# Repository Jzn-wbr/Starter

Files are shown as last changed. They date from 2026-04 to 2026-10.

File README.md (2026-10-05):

<div align="center">

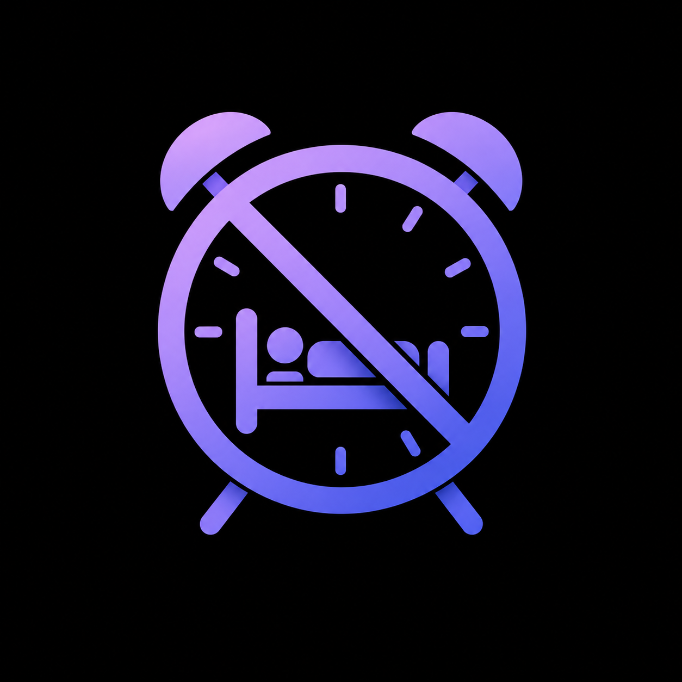
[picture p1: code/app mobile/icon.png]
Logo de l’application mobile Réveil


# Réveil

### Un réveil qui vous aide vraiment à sortir du lit.

Un système de réveil connecté qui combine une station audio, un bracelet de mouvement et une application mobile pour transformer le réveil en un vrai départ de journée.

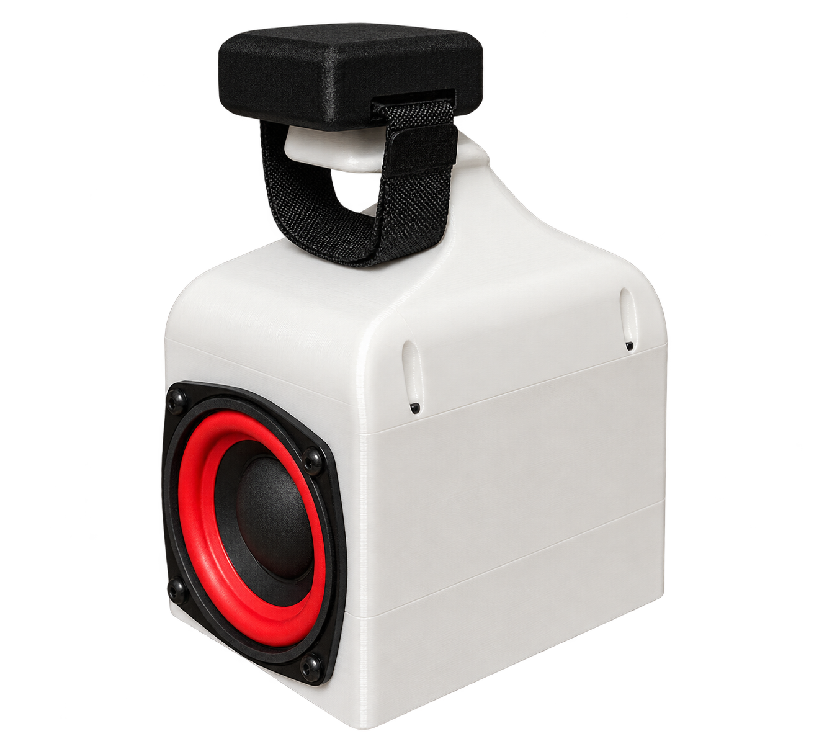
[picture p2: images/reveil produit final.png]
Version finale de la station audio


**Projet personnel · Version finale du produit**

</div>

## L’idée

Les réveils classiques s’arrêtent d’une pression sur un bouton. Celui-ci est pensé pour rendre le retour au sommeil beaucoup plus difficile : l’alarme démarre à l’heure choisie et ne se calme qu’après avoir détecté une activité réelle grâce au bracelet.

Pas de bouton snooze. Pas de négociation avec soi-même à 7 h 30.

## Une expérience en trois éléments

| | Rôle |
| --- | --- |
| **La station** | Le centre du système : elle déclenche l’alarme, diffuse la musique et supervise le réveil. |
| **Le bracelet** | Il détecte les mouvements et confirme que la journée a réellement commencé. |
| **L’application** | Elle permet de choisir l’heure, la musique et de vérifier que les appareils sont prêts. |

<p align="center">
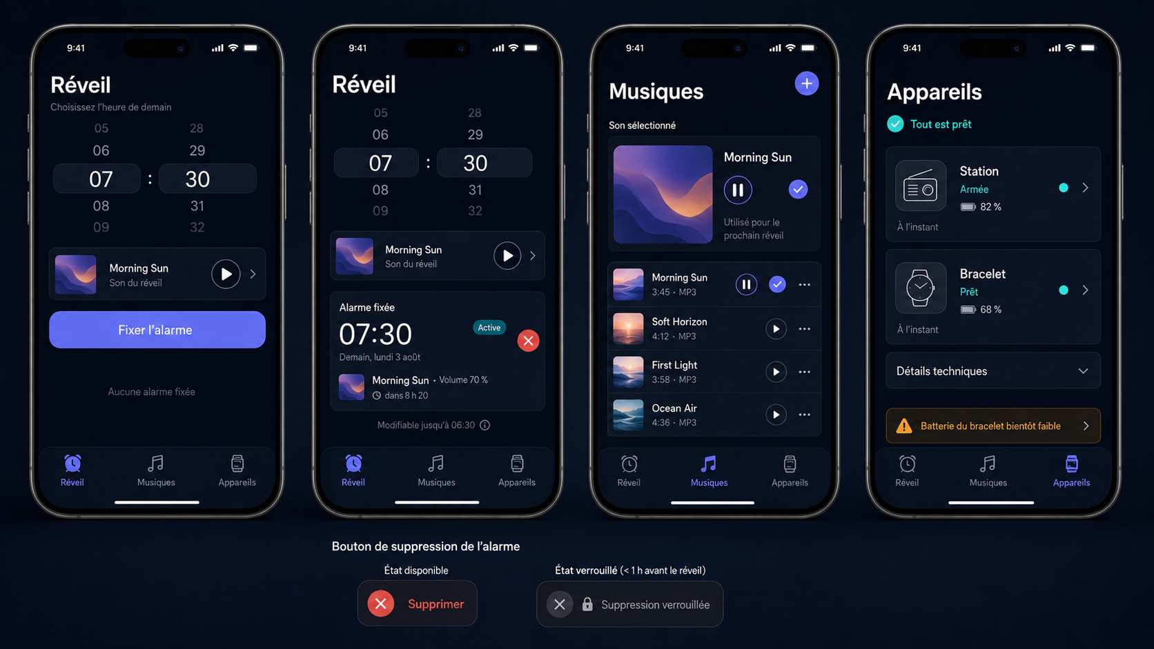
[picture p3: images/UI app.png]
Interface mobile de configuration du réveil
  
</p>

## Comment ça marche

1. Choisissez une heure et votre son de réveil dans l’application.
2. La station se prépare pour le lendemain et synchronise la configuration.
3. À l’heure prévue, la musique démarre sur la station.
4. Le bracelet mesure votre activité pendant une fenêtre dédiée.
5. Quand le mouvement est confirmé, le réveil peut enfin s’arrêter.

L’objectif : remplacer le réflexe « encore cinq minutes » par un réveil plus franc, plus personnel et plus difficile à ignorer.

## En images

<div align="center">
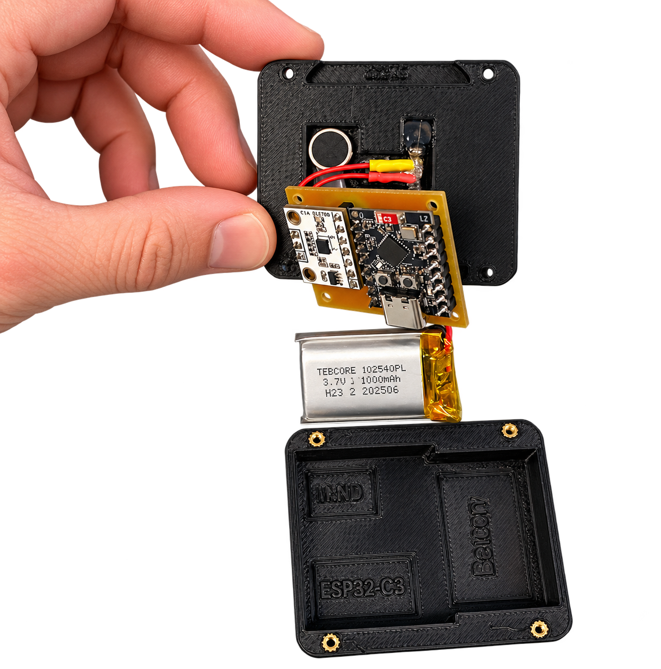
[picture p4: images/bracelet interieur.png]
Électronique et batterie du bracelet
  
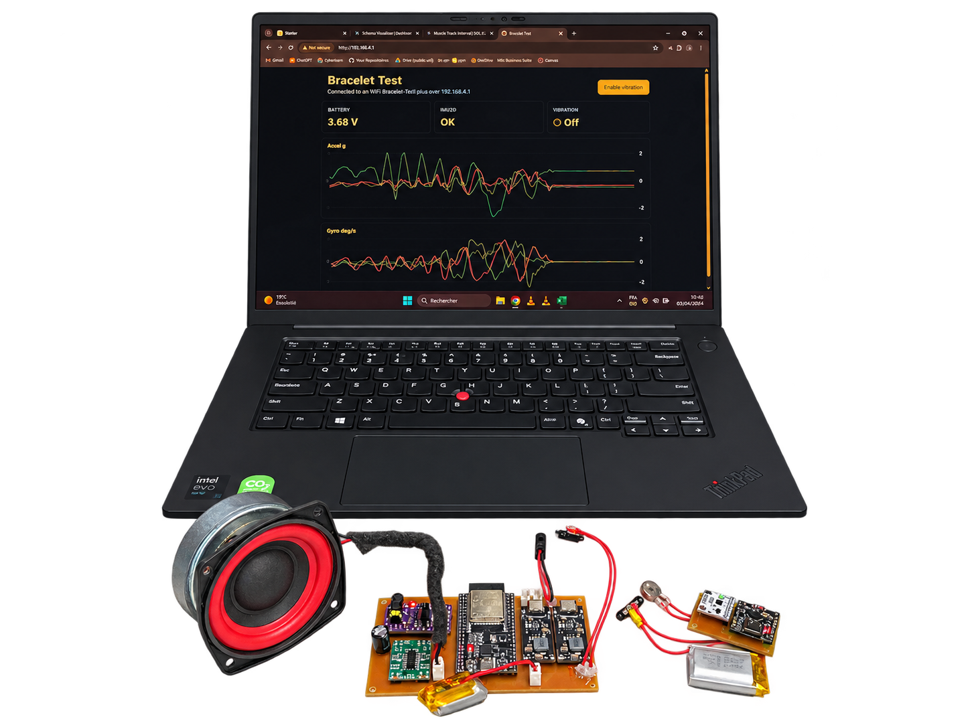
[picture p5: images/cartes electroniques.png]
Cartes électroniques et station audio
  
</div>

## Une base ouverte pour un objet complet

Ce dépôt rassemble l’application mobile, le firmware de la station, le firmware du bracelet, les schémas électroniques et la documentation du système. Il présente la version finale du produit, pensée comme un réveil fiable, agréable à utiliser et réellement efficace.

> Le système est conçu pour un usage personnel. Les choix techniques et les fonctionnalités peuvent encore évoluer.

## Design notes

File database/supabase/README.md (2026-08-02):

# Supabase v1 schema

`v1_schema.sql` is the concrete database contract for the personal wake-up prototype.

Apply it in the Supabase SQL editor or through the Supabase CLI against the target project. It creates:

- `alarm_plan`
- `alarm_audio_selection`
- `music_tracks`
- `station_status`
- `bracelet_status`
- storage bucket `wake-up-music`
- prototype-only anon read/write policies

The anon policies are intentionally permissive for the no-auth v1 prototype. They are not production-ready security.

## V1 table split

The schema intentionally keeps one active `main` row per responsibility:

- `alarm_plan`: whether and when the next alarm should happen.
- `alarm_audio_selection`: what the next alarm should play and at what volume.
- `music_tracks`: uploaded wake-up sounds.
- `station_status`: station state and station-side problem reporting.
- `bracelet_status`: latest bracelet state, energy window, vibration state, and battery voltage as seen and published by the station.

This split favors readability over the smallest possible number of Supabase reads. The station should load `alarm_plan` and `alarm_audio_selection` together, then cache the last valid combined configuration locally.
Bracelet energy remains station-side alarm input; the station does not stream energy to Supabase at bracelet telemetry rate.

This file is the current v1 schema, not a reversible migration. If an older prototype database already contains `alarm_config` or `device_status`, migrate or drop those old tables manually after preserving any data you still need.

## Mermaid overview

```mermaid
erDiagram
  MUSIC_TRACKS {
    text id PK
    text title
    text storage_path UK
    text public_url
    boolean is_available
    timestamptz created_at
  }

  ALARM_PLAN {
    text id PK "always main"
    boolean enabled
    date alarm_date
    time alarm_time
    text timezone
    integer revision
    timestamptz updated_at
  }

  ALARM_AUDIO_SELECTION {
    text id PK "always main"
    audio_source_v1 audio_source
    text selected_track_id FK
    integer volume_percent
    timestamptz updated_at
  }

  STATION_STATUS {
    text id PK "always main"
    station_state_v1 station_state
    problem_code_v1 problem_code
    text problem_message
    integer active_alarm_revision
    numeric station_battery_voltage
    timestamptz updated_at
  }

  BRACELET_STATUS {
    text id PK "always main"
    bracelet_state_v1 bracelet_state
    problem_code_v1 problem_code
    text problem_message
    numeric bracelet_battery_voltage
    bigint bracelet_last_seen_ms
    integer bracelet_energy
    integer bracelet_energy_valid_ms
    integer bracelet_energy_threshold
    integer energy_mute_remaining_ms
    boolean bracelet_vibrating
    timestamptz updated_at
  }

  MUSIC_TRACKS ||--o| ALARM_AUDIO_SELECTION : selected_by
```

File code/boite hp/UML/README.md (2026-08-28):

# Station UML

This folder contains PlantUML source files for the bedside station firmware architecture.

Rules:

- Commit `.puml` source files.
- Update diagrams manually when architecture, state machines, module boundaries, ESP-NOW flow, Supabase flow, audio flow, fallback behavior, or fault handling changes.
- Do not regenerate diagrams automatically during normal PlatformIO builds.
- Generated image exports such as `.png` or `.svg` are optional local review artifacts; the `.puml` files are the source of truth.

Suggested starting diagrams:

- `station_state_machine.puml`
- `communication_flow.puml`

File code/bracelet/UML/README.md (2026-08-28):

# Bracelet UML

This folder contains PlantUML source files for the bracelet firmware architecture.

Rules:

- Commit `.puml` source files.
- Update diagrams manually when architecture, state machines, module boundaries, BMI270 flow, activity validation, ESP-NOW telemetry, battery readiness, or fault handling changes.
- Do not regenerate diagrams automatically during normal PlatformIO builds.
- Generated image exports such as `.png` or `.svg` are optional local review artifacts; the `.puml` files are the source of truth.

Suggested starting diagrams:

- `bracelet_firmware_flow.puml`
- `esp_now_packet_flow.puml`

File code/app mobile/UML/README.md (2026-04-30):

# Mobile App UML

This folder contains PlantUML source files for the mobile PWA.

Rules:

- Commit `.puml` source files.
- Keep at least one UML use-case diagram for the v1 app workflow.
- Update diagrams manually when app use cases, user-facing flows, Supabase behavior, or status display behavior changes.
- Do not regenerate diagrams automatically during normal app builds or dev-server runs.
- Generated image exports such as `.png` or `.svg` are optional local review artifacts; the `.puml` files are the source of truth.

Current diagrams:

- `use_cases.puml`

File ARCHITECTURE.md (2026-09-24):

# System Architecture And Contracts

This file defines the shared contracts between the three code areas:

- `code/app mobile`: Vue/Vite PWA.
- `code/boite hp`: bedside station firmware.
- `code/bracelet`: bracelet firmware.

Each subsystem should be developed independently against these contracts. Do not change a contract without updating this file and the affected `AGENTS.md` files.

## Core Architecture

The station is the central alarm authority. The app configures the alarm through Supabase. The bracelet only reports activity to the station.

Target v1 communication paths:

- App -> Supabase: upload music, select music, configure next alarm.
- Station -> Supabase: read alarm plan, read selected music URL, write station/problem state.
- Bracelet -> Station: send activity and battery/fault telemetry over ESP-NOW.
- Station -> Bracelet: send ESP-NOW control messages such as current alarm phase, acknowledgements, vibration requests, or threshold profile.
- App -> Station: no direct communication in v1.
- App -> Bracelet: no direct communication in v1.
- Bracelet -> Supabase: no direct communication in v1.

ESP-NOW is the target station/bracelet link. The station remains associated with the configured home WiFi for NTP, Supabase, and music streaming, while ESP-NOW shares the station's current 2.4 GHz channel. The bracelet does not join the router: it scans ESP-NOW channels until a valid paired station control is found, locks to that channel while controls continue, and resumes scanning after a control timeout. ESP-NOW range, channel reacquisition, latency, and battery life must be tested physically.

## Supabase V1 Schema

Use these exact table names and field names for v1 unless this file is updated first. The concrete Supabase SQL definition is in `database/supabase/v1_schema.sql`. The app and station must code against that SQL schema.

The v1 schema is prototype-only from a security perspective: anon clients may read and write the v1 tables and the public wake-up music bucket. This is acceptable only for the personal no-auth prototype, not for production.

### `alarm_plan`

Single active-row table for whether and when the next wake-up should happen.

- `id`: text, always `main` for v1.
- `enabled`: boolean.
- `alarm_date`: SQL `date`, local date for the next alarm.
- `alarm_time`: SQL `time without time zone`, `HH:MM` 24-hour local time at the app/station boundary.
- `timezone`: IANA timezone string, for example `Europe/Zurich`.
- `revision`: integer incremented by the app on each saved config.
- `updated_at`: SQL `timestamptz`, updated automatically by the database on row update.

### `alarm_audio_selection`

Single active-row table for what the next wake-up should play.

- `id`: text, always `main` for v1.
- `audio_source`: `track` or `fallback`; `fallback` means the local station fallback sound is intentionally selected.
- `selected_track_id`: text referencing `music_tracks.id`; required when `audio_source` is `track`, null when `audio_source` is `fallback`.
- `volume_percent`: integer `0..100`, playback volume requested for the next alarm.
- `updated_at`: SQL `timestamptz`, updated automatically by the database on row update.

Station rule: cache the last valid combined alarm configuration from `alarm_plan` and `alarm_audio_selection` locally. If Supabase is unreachable later but the cached config is still for the next alarm and the station has valid time, the station may use the cached config.

### `music_tracks`

Library of uploaded wake-up sounds.

- `id`: text primary key, generated as a UUID string by default.
- `title`: display name shown in the app.
- `storage_path`: Supabase Storage path.
- `public_url`: playable URL used by the station in the no-auth prototype.
- `is_available`: boolean.
- `created_at`: SQL `timestamptz`.

Use the Supabase Storage bucket `wake-up-music` for uploaded audio files. V1 allows `audio/mpeg`, `audio/wav`, `audio/ogg`, and `audio/mp4` up to 50 MiB per file.

Avoid storing duration, waveform, tags, statistics, playlist order, or user metadata before v1 needs them.

### `station_status`

Single station-published status row read by the app.

- `id`: text, always `main` for v1.
- `station_state`: one of the station states below.
- `problem_code`: one of the problem codes below, or `none`.
- `problem_message`: short human-readable diagnostic text.
- `active_alarm_revision`: latest `alarm_plan.revision` loaded by the station.
- `station_battery_voltage`: station battery terminal voltage in volts, or `null` if unknown.
- `updated_at`: SQL `timestamptz`, updated automatically by the database on row update.

The app reads this status. The app must not infer alarm authority from it.

### `bracelet_status`

Single station-published row for the latest bracelet state as seen by the station.

- `id`: text, always `main` for v1.
- `bracelet_state`: latest bracelet state as seen by the station, or `unknown`.
- `problem_code`: one of the problem codes below, or `none`.
- `problem_message`: short human-readable diagnostic text.
- `bracelet_battery_voltage`: bracelet battery terminal voltage in volts, or `null` if unknown.
- `bracelet_last_seen_ms`: station uptime timestamp for the last bracelet packet, or `null`.
- `bracelet_energy`: latest 200 ms energy window reported by the bracelet.
- `bracelet_energy_valid_ms`: measured time inside that 200 ms window, excluding vibration and settling time.
- `bracelet_energy_threshold`: station threshold used to mute alarm audio for v1. The current firmware default is `1000000`.
- `energy_mute_remaining_ms`: remaining station-side mute time produced by bracelet energy.
- `bracelet_vibrating`: whether the bracelet vibration motor is currently active.
- `updated_at`: SQL `timestamptz`, updated automatically by the database on row update.

The app reads this status. The bracelet does not write to Supabase in v1.

### Problem Codes

Use these v1 problem codes:

- `none`
- `supabase_unavailable`
- `time_unknown`
- `no_valid_alarm_config`
- `music_stream_failed`
- `fallback_audio_failed`
- `bracelet_missing`
- `bracelet_low_battery`
- `sensor_fault`

## System States

The station should expose one clear state at a time:

- `idle`: no alarm armed.
- `armed`: next alarm is configured and valid.
- `ringing`: alarm audio is active.
- `validating_activity`: alarm is active and bracelet activity is being evaluated.
- `stopped`: alarm window ended after bracelet activity monitoring.
- `fault`: alarm cannot run correctly because of a blocking issue.

The bracelet should expose:

- `ready`: enough battery and sensor link is usable.
- `low_battery`: battery may be insufficient for reliable wake-up validation.
- `fault`: sensor, power, or firmware state prevents reliable validation.

The app should display station and bracelet states without becoming the alarm authority.

## Station State Transitions

Allowed station transitions for v1:

- `idle -> armed`: app has saved a valid enabled alarm and station loaded it.
- `idle -> fault`: blocking configuration, time, audio, or bracelet readiness problem.
- `armed -> idle`: app disables the next alarm.
- `armed -> ringing`: alarm time is reached and prerequisites are valid.
- `armed -> fault`: a blocking problem appears before alarm time.
- `ringing -> validating_activity`: bracelet energy reaches `1000000` during the alarm window, so alarm audio is muted for 10 seconds while monitoring continues.
- `ringing -> ringing`: bracelet packets are lost for more than `3s`; publish `bracelet_missing`, keep alarm audio playing, and resume movement detection automatically when packets return.
- `ringing -> fault`: station audio output fails.
- `ringing -> stopped`: the 10-minute alarm activity window has ended.
- `validating_activity -> ringing`: the 10-second energy mute and the pre-unmute warning of up to three bracelet vibrations expire before the 10-minute window has ended.
- `validating_activity -> stopped`: the 10-minute alarm activity window has ended.
- `validating_activity -> validating_activity`: bracelet packets are lost for more than `3s`; publish `bracelet_missing` but honor the remaining confirmed movement mute.
- `validating_activity -> ringing`: the confirmed movement mute expires and no vibration acknowledgement or new movement event prevents audio from resuming.
- `validating_activity -> fault`: station audio output fails.
- `stopped -> idle`: alarm cycle is complete.
- `fault -> idle`: user fixes the issue and station reloads a valid disabled/no-alarm state.
- `fault -> armed`: user fixes the issue and station reloads a valid enabled alarm.

Do not add a normal stop or snooze transition from `ringing` or `validating_activity`. The v1 alarm stops only when the fixed 10-minute activity window ends; bracelet energy only mutes alarm audio during that window.

When the bracelet observes the station transition from `ringing` or `validating_activity` to `stopped`, it emits one completion signal made of four fast vibration pulses. Each pulse lasts `150ms` and starts `300ms` after the previous one. This local indication means the 10-minute wake-up window is complete and the bracelet may be removed. Repeated `stopped` controls do not replay the signal.

## Failure Policy

The product is designed by the lucid user from the evening for the tired user in the morning. Battery preparation and normal readiness are the user's responsibility: the bracelet should be placed on the station and the station should be plugged in overnight.

If there is a blocking bug or technical fault that prevents normal operation, the station should not create a fake sense of reliability. It should enter `fault`, avoid starting a broken alarm flow, and publish a clear problem state for the app.

Blocking faults before alarm start include:

- No valid combined `alarm_plan` and `alarm_audio_selection` can be loaded and no valid cached config exists.
- Bracelet is missing or not ready when bracelet validation is required.
- Bracelet battery is below the required threshold.
- Bracelet reports `fault`.
- Station cannot determine time.
- Station audio output cannot be initialized.

Music streaming failure is not a reason to skip the alarm. If the selected Supabase music cannot be streamed at wake-up time, the station must use a small local fallback alarm sound that fits ESP memory constraints.

Network or Supabase failures should be visible in station logs and in app-readable status when possible.

If the bracelet disappears for more than `3s` while ringing, publish `bracelet_missing` and keep alarm audio playing. If a confirmed movement mute is already active, honor its original deadline instead of cancelling it; once it expires, resume audio after the vibration acknowledgement policy below. When packets return, clear the missing problem and process any still-valid retransmitted movement event. Do not mark the alarm revision complete because of bracelet packet loss. If station audio itself fails, prefer `fault` over a fake alarm state.

## Battery Readiness Contract

Use these v1 defaults unless physical testing proves they are wrong:

- Bracelet `ready`: battery is at least `30%` and sensor init succeeds.
- Bracelet `low_battery`: battery is below `30%`.
- Bracelet blocking low battery: battery is below `20%` before alarm start.
- Station should publish `bracelet_low_battery` before bedtime if seen.
- Station should enter `fault` before alarm start if bracelet battery is below the blocking threshold.

If battery voltage cannot be measured yet, report `null` and document the limitation. Do not fake battery precision.

Supabase stores raw battery voltage for station and bracelet status. User-facing battery percentages are derived by the PWA from the voltage, so changing the display curve does not require a database migration.

Station battery voltage is measured on station GPIO34 through a 2:1 voltage divider: `Vbat = 2 * Vadc`.

## Bracelet/Station ESP-NOW Contract

Use compact binary packets. All packets start with:

- `magic`: uint32 value identifying Starter traffic before any packet is parsed.
- `protocol_version`: `6`. Older packets are rejected; station and bracelet firmware must be updated together.
- `message_type`: enum below.
- `sender_role`: `station` or `bracelet`.
- `device_id`: 6-byte MAC address.
- `sequence`: uint32 incrementing counter.
- `uptime_ms`: uint32 sender uptime.

### Message Types

- `1`: `bracelet_status`, bracelet -> station.
- `2`: `station_control`, station -> bracelet.

### ESP-NOW `bracelet_status` Packet

Fields:

- `bracelet_state`: enum from System States.
- `battery_voltage_mv`: uint16 bracelet battery terminal voltage in millivolts, or `0` if unknown.
- `fault_code`: problem code enum, or `none`.
- `vibrating`: boolean indicating whether the vibration motor is currently active.
- `energy`: uint32 energy measured over the latest 200 ms window.
- `energy_valid_ms`: uint16 measured milliseconds in that window, excluding bracelet vibration/settling.
- `boot_session_id`: uint32 random non-zero identifier regenerated at bracelet boot.
- `movement_event_id`: uint32 identifier of the latest unacknowledged qualifying energy window, or `0`.
- `movement_event_uptime_ms`: bracelet uptime when that energy window ended.
- `movement_event_energy`: uint32 energy of the retained event.
- `movement_event_valid_ms`: valid measured milliseconds of the retained event.
- `vibration_ack_id`: latest vibration request identifier for which the motor actually started.

Both devices register an unencrypted ESP-NOW broadcast peer. Default send rate:

- Bracelet status is sent every `10s` outside an active alarm and at `5 Hz` while ringing or validating activity. Qualifying movement during the alarm, vibration acknowledgement, first contact, faults, and important state changes force an immediate status. The station must not mirror high-rate telemetry to Supabase.
- Station control is sent every `5s` outside an alarm, every `700ms` during an alarm, and immediately on important state changes.

Station timeout rules:

- If no bracelet packet for `25s` while `armed`, publish `bracelet_missing`.
- If no bracelet packet for `3s` while `ringing`, publish `bracelet_missing` and keep alarm audio playing.
- If no bracelet packet for `3s` during an existing movement mute, publish `bracelet_missing` but preserve the mute deadline. A delayed event can recover only the unelapsed part of its original 10-second interval.
- After a Supabase HTTPS failure, the station waits `30s` before trying another Supabase request. This avoids repeated TLS allocation failures during low-memory recovery after streaming.

### `station_control`

Fields:

- `station_state`: enum from System States.
- `vibration_request`: boolean; forced false for the first `15s` after the configured alarm time, then true while the station is producing audible alarm audio and during the pre-unmute warning of up to three vibrations before audio resumes after an energy mute. Audio, movement processing, mute timing, and the fixed activity window remain active during the initial vibration-free interval.
- `acknowledged_boot_session_id`: bracelet boot session associated with the acknowledged movement event.
- `acknowledged_movement_event_id`: latest movement event accepted or intentionally ignored by the station.
- `vibration_request_id`: non-zero identifier regenerated whenever vibration changes from not requested to requested.

The bracelet scans WiFi channels 1 through 13 every `300ms` until it receives a valid `station_control`, then locks to that channel while controls continue. After `15s` without a valid control, it resumes channel scanning. Reliable movement delivery and confirmed pre-unmute vibration use the acknowledgements carried by subsequent station control packets.
When `vibration_request` is true, the bracelet pulses its motor instead of holding it continuously on. During audible ringing, the default remains `500ms` on every `4s`. During the `validating_activity` pre-unmute warning, each pulse also lasts `500ms`, but the starts occur at `0s`, `4s`, and `6s`; audio resumes approximately `1s` after the third pulse starts. A new valid movement event after the first or second pulse cancels the warning request and starts a new movement mute, so the remaining warning pulses are not required. BMI270 energy is ignored while the motor is active and during the short settling time after it stops. When the motor first starts for a request, the bracelet echoes its identifier in `vibration_ack_id` and forces a status response.
The station broadcasts `station_control` over ESP-NOW on its current home-WiFi channel. Controls are sent every `5s` outside an alarm, every `700ms` during an alarm, and immediately for important state changes. ESP-NOW loss is handled by the existing event retention, identifiers, retransmission, and application acknowledgements.

The first valid exchange pairs the two device MAC identifiers in NVS. Later packets from another device identifier are rejected. Replacing a paired device requires erasing NVS/flash before reflashing. If the station changes home-WiFi channel after reconnecting, the bracelet reacquires it through channel scanning without clearing the pairing.

The station remains authoritative. Bracelet energy is input to the station, not a direct stop command.

## Activity Window Contract

Use these v1 defaults unless physical testing proves they are wrong:

- The station opens a fixed `10min` activity window at the configured alarm time.
- The station starts alarm audio at the configured time but does not request bracelet vibration during the first `15s`. Once those `15s` have elapsed, the existing vibration behavior resumes; all movement and audio-muting rules continue throughout the delay.
- During that window, the station plays alarm audio when bracelet energy is below threshold or missing.
- If a bracelet energy window reaches the station threshold, currently `1000000`, the bracelet retains it as a movement event for up to `10s` and retransmits it until acknowledged. The station revalidates the event and mutes alarm output with station `XSMT` on GPIO26 for the unelapsed part of the original 10-second interval. For example, an event received at age `4s` produces `6s` of mute.
- Duplicate, out-of-order, pre-alarm, invalid, or at-least-10-second-old movement events do not restart the mute. A newer valid event may extend the existing deadline.
- When the mute expires, the station keeps `XSMT` muted and requests vibration with a new identifier. After matching `vibration_ack_id`, the bracelet may emit three `500ms` pulses: the second starts `4s` after the first and the third starts `2s` after the second. Audio resumes approximately `1s` after the third pulse starts, including the `500ms` jitter grace. A new valid movement event after any pulse immediately cancels the warning request and restarts only that event's remaining 10-second mute interval; therefore the bracelet may vibrate only once or twice when the user moves in time. Without acknowledgement after `3s`, the station resumes alarm audio conservatively. If the mute expires during the initial 15-second vibration-free interval, audio remains muted until that interval ends and the warning can run.
- When the 10-minute window ends, the station stops alarm audio and marks the alarm revision complete, regardless of energy history.

The bracelet computes energy over 200 ms windows and retains threshold candidates for reliable transport. The station revalidates every event and remains responsible for whether audio should play and when the alarm revision is complete.

## Fallback Sound Contract

The station must have a local fallback alarm sound for cases where Supabase audio is unreachable at wake-up time.

The fallback should:

- Use very little memory.
- Be loud and recognizable enough to wake the user.
- Not depend on network availability.
- Be documented in the station firmware.
- Prefer generated tones or a very small embedded sample over a large stored audio file.

The fallback sound does not replace Supabase music as the normal path.

## Secrets And Environment Contract

Do not commit real secrets.

Allowed:

- `secrets.example.h`
- `.env.example`
- documented placeholder values

Forbidden:

- `secrets.h`
- `.env`
- `.env.local`
- Supabase service-role keys
- WiFi passwords
- private storage tokens

The PWA may use Supabase public anon configuration for the no-auth prototype, but agents must label that setup as prototype-only.

## UML Documentation Contract

The app, station, and bracelet projects must keep human-readable PlantUML diagrams:

- `code/app mobile/UML`
- `code/boite hp/UML`
- `code/bracelet/UML`

Agents must update the relevant `.puml` files when changing:

- app use cases or user-facing flows;
- class/module boundaries;
- state machines;
- ESP-NOW packet flow, channel discovery, and pairing;
- Supabase/config flow in station firmware;
- activity validation flow in bracelet firmware;
- fallback or fault-handling architecture.

The app must keep at least a simple UML use-case diagram. The `.puml` files are maintained manually with code changes. They should not be regenerated automatically by PlatformIO builds, app dev servers, or normal agent runs.

## Implementation Order

Recommended order for agents:

1. Keep this architecture contract current.
2. Apply and validate the concrete Supabase schema in `database/supabase/v1_schema.sql`.
3. Implement station time sync, alarm state machine, and fallback sound.
4. Implement app upload, music selection, alarm plan editing, and status display.
5. Implement bracelet BMI270 activity detection.
6. Implement ESP-NOW bracelet/station telemetry.
7. Integrate and validate the complete wake-up flow.

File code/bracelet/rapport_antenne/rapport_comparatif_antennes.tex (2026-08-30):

\documentclass[10pt,a4paper]{article}

\usepackage[T1]{fontenc}
\usepackage[utf8]{inputenc}
\usepackage[french]{babel}
\usepackage{lmodern}
\usepackage{microtype}
\usepackage[a4paper,margin=16mm,top=14mm,bottom=15mm]{geometry}
\usepackage{xcolor}
\usepackage{colortbl}
\usepackage{graphicx}
\usepackage{booktabs}
\usepackage{tabularx}
\usepackage{array}
\usepackage{enumitem}
\usepackage{tikz}
\usepackage{pgfplots}
\usepackage{tcolorbox}
\usepackage{fancyhdr}
\usepackage{lastpage}
\usepackage[hidelinks]{hyperref}
\usepackage{siunitx}

\pgfplotsset{compat=1.18}
\sisetup{locale=FR,output-decimal-marker={,}}
\definecolor{navy}{HTML}{17365D}
\definecolor{blue}{HTML}{1976A3}
\definecolor{cyan}{HTML}{20A4C7}
\definecolor{green}{HTML}{16856B}
\definecolor{orange}{HTML}{E58B2A}
\definecolor{red}{HTML}{C94B4B}
\definecolor{ink}{HTML}{243447}
\definecolor{muted}{HTML}{637381}
\definecolor{paper}{HTML}{F4F7FA}
\definecolor{line}{HTML}{D8E1E8}

\hypersetup{pdftitle={Comparaison des antennes Wi-Fi du bracelet},pdfauthor={Projet bracelet}}
\setlength{\parindent}{0pt}
\setlength{\parskip}{4pt}
\setlength{\headheight}{21pt}
\setlist[itemize]{leftmargin=5mm,itemsep=2pt,topsep=2pt}
\renewcommand{\arraystretch}{1.16}
\newcolumntype{Y}{>{\raggedright\arraybackslash}X}
\newcolumntype{C}[1]{>{\centering\arraybackslash}p{#1}}

\pagestyle{fancy}
\fancyhf{}
\fancyhead[L]{\small\color{muted}BRACELET \textbullet{} ÉVALUATION RF}
\fancyhead[R]{\small\color{muted}04 août 2026}
\fancyfoot[L]{\small\color{muted}Analyse des scans Wi-Fi 2,4 GHz}
\fancyfoot[R]{\small\color{muted}\thepage/\pageref{LastPage}}
\renewcommand{\headrulewidth}{0.4pt}
\renewcommand{\headrule}{\hbox to\headwidth{\color{line}\leaders\hrule height \headrulewidth\hfill}}

\newcommand{\sectiontitle}[2]{%
  {\color{navy}\fontsize{19}{21}\selectfont\bfseries #1}\par
  {\color{muted}\small #2}\par\vspace{4pt}
  {\color{cyan}\rule{19mm}{2pt}}\vspace{5pt}
}
\newcommand{\metric}[3]{%
\begin{tcolorbox}[boxrule=0pt,arc=2mm,colback=#1!7,left=3mm,right=3mm,top=2mm,bottom=2mm]
{\color{#1}\fontsize{18}{19}\selectfont\bfseries #2}\par
{\color{muted}\footnotesize #3}
\end{tcolorbox}}
\newtcolorbox{decisionbox}{colback=green!6,colframe=green,boxrule=.7pt,arc=2mm,left=4mm,right=4mm,top=3mm,bottom=3mm}
\newtcolorbox{warningbox}{colback=orange!7,colframe=orange,boxrule=.7pt,arc=2mm,left=4mm,right=4mm,top=3mm,bottom=3mm}

\begin{document}

% --- Page 1 ---------------------------------------------------------------
\thispagestyle{empty}
\begin{tikzpicture}[remember picture,overlay]
  \fill[navy] (current page.north west) rectangle ([yshift=-58mm]current page.north east);
  \fill[cyan] ([yshift=-58mm]current page.north west) rectangle ([yshift=-61mm]current page.north east);
  \draw[cyan!35,line width=.6pt] ([xshift=-40mm,yshift=-18mm]current page.north east) circle (19mm);
  \draw[cyan!35,line width=.6pt] ([xshift=-40mm,yshift=-18mm]current page.north east) circle (12mm);
  \fill[cyan] ([xshift=-40mm,yshift=-18mm]current page.north east) circle (2mm);
\end{tikzpicture}
\vspace*{5mm}
{\color{cyan}\small\bfseries RAPPORT D'ESSAIS \textbullet{} WI-FI 2,4 GHz}\par
\vspace{7mm}
{\color{white}\fontsize{27}{30}\selectfont\bfseries Comparaison des antennes\\du bracelet}\par
\vspace{4mm}
{\color{white!78}\large Analyse quantitative, tendances et recommandation de conception}\par
\vspace{18mm}

\begin{decisionbox}
{\color{green}\large\bfseries Décision sur les données actuelles : antenne 50 mm, verticale}\par
Elle offre le meilleur ensemble de résultats : niveau des signaux dominants, réception des points d'accès éloignés et régularité. La \textbf{45 mm} est le meilleur compromis si l'encombrement impose une réduction. La décision reste à confirmer \textbf{boîtier fermé et au poignet}, conditions non mesurées pour ces deux candidates.
\end{decisionbox}

\begin{minipage}[t]{0.32\textwidth}
\metric{blue}{39}{scans analysés}
\end{minipage}\hfill
\begin{minipage}[t]{0.32\textwidth}
\metric{cyan}{1\,043}{détections Wi-Fi}
\end{minipage}\hfill
\begin{minipage}[t]{0.32\textwidth}
\metric{green}{+34,2 dB}{gain 50 mm vs origine\newline(moyenne du top 5)}
\end{minipage}

\vspace{3mm}
\begin{tcolorbox}[colback=paper,colframe=line,boxrule=.5pt,arc=2mm,title={\color{navy}\bfseries Lecture en 30 secondes},fonttitle=\small]
\begin{itemize}
  \item \textbf{50 mm :} 33,6 réseaux par scan et top 5 à \(-44,2\) dBm ; meilleur choix radio global.
  \item \textbf{45 mm :} 33,1 réseaux et top 5 à \(-45,9\) dBm ; seulement 1,7 dB derrière sur les signaux dominants, mais 3,6 dB derrière sur la passerelle de référence.
  \item \textbf{41 mm verticale :} très bon signal proche, mais moins de réseaux (29,8) et réception distante moins convaincante.
  \item \textbf{Intégration :} la 41 mm perd 10,2 dB couchée, puis encore 7,1 dB avec le boîtier fermé sur l'indicateur top 5.
\end{itemize}
\end{tcolorbox}

\vfill
{\color{muted}\small Source : \texttt{app mobile/mesures.txt} \textbullet{} Conditions déclarées identiques sauf mention contraire \textbullet{} RSSI en dBm (moins négatif = meilleur)}
\newpage

% --- Page 2 ---------------------------------------------------------------
\sectiontitle{1. Protocole et méthode}{Une comparaison centrée sur la qualité de réception et la robustesse de la décision}

\begin{minipage}[t]{0.49\textwidth}
\textbf{Configurations étudiées}
\begin{itemize}
  \item antenne d'origine : 6 scans ;
  \item fil de section 1 mm, boucle 18 mm : longueurs 50, 48, 45 et 41 mm, en position verticale ;
  \item antenne 41 mm couchée ;
  \item antenne 41 mm couchée, boîtier fermé.
\end{itemize}
\end{minipage}\hfill
\begin{minipage}[t]{0.49\textwidth}
\textbf{Échantillonnage}
\begin{itemize}
  \item 39 scans au total, groupes de 4 à 9 scans ;
  \item environnement et conditions annoncés identiques ;
  \item chaque ligne fournit SSID, canal et RSSI ;
  \item aucune adresse BSSID ni mesure d'émission n'est fournie.
\end{itemize}
\end{minipage}

\vspace{2mm}
\textbf{Indicateurs retenus}\par\smallskip
\begin{tabularx}{\textwidth}{>{\bfseries\color{navy}}p{31mm} Y p{43mm}}
\toprule
Indicateur & Rôle dans la décision & Précaution d'interprétation \\
\midrule
Réseaux visibles & Couverture et capacité à détecter des signaux faibles & Dépend de l'occupation radio instantanée \\
Moyenne du top 5 & Qualité des cinq meilleures réceptions de chaque scan & Plus robuste que la moyenne de toutes les lignes \\
Points d'accès repères & Comparaison de liens identifiables par SSID et canal & Un SSID peut regrouper plusieurs BSSID \\
Écart-type entre scans & Répétabilité à court terme & Les groupes n'ont pas tous la même taille \\
Taux de détection & Robustesse sur les réseaux faibles & Sensible au seuil et aux trames diffusées \\
\bottomrule
\end{tabularx}

\vspace{5mm}
\begin{warningbox}
\textbf{Pourquoi la moyenne de tous les RSSI serait trompeuse.} Une meilleure antenne détecte davantage de réseaux faibles ; ces nouvelles valeurs très négatives peuvent dégrader sa moyenne brute. Le rapport privilégie donc le top 5, les points d'accès repères et le nombre de réseaux.
\end{warningbox}

\vspace{3mm}
\textbf{Limites à conserver dans la décision}
\begin{itemize}
  \item Il s'agit de \textbf{scans en réception}. Ils ne mesurent ni débit, ni pertes ESP-NOW, ni latence, ni puissance effectivement rayonnée.
  \item L'absence de BSSID empêche d'identifier sans ambiguïté les différents points d'accès portant le même SSID.
  \item Une seule géométrie (41 mm) est mesurée couchée et boîtier fermé ; l'effet du boîtier ne peut pas être transposé exactement aux autres longueurs.
  \item Le corps, la batterie, le mouvement et l'orientation du poignet peuvent désaccorder l'antenne. La recommandation est donc une \textbf{sélection pour le prochain prototype}, pas une validation RF finale.
\end{itemize}

\begin{tcolorbox}[colback=blue!5,colframe=blue!35,boxrule=.5pt,arc=2mm]
\textbf{Convention :} un RSSI plus proche de 0 est meilleur. Un écart de 3 dB correspond approximativement à un facteur 2 de puissance reçue ; cette conversion reste indicative car les RSSI embarqués ne sont pas des mesures de laboratoire calibrées.
\end{tcolorbox}
\newpage

% --- Page 3 ---------------------------------------------------------------
\sectiontitle{2. Résultats globaux}{Les trois meilleures géométries détectent environ 33 réseaux, mais leur qualité de signal diffère}

\begin{minipage}[t]{0.51\textwidth}
\centering
\textbf{Réseaux visibles par scan}\par\smallskip
\begin{tikzpicture}
\begin{axis}[
  width=.95\linewidth,height=58mm,
  xbar,xmin=0,xmax=40,
  symbolic y coords={Origine,50 mm,48 mm,45 mm,41 mm,41 couchée,41 boîte},
  ytick=data,y dir=reverse,
  xlabel={moyenne},
  nodes near coords,nodes near coords align={horizontal},
  every node near coord/.append style={font=\scriptsize},
  tick label style={font=\scriptsize},label style={font=\scriptsize},
  axis line style={draw=line},grid=major,grid style={draw=line!70},
  bar width=4.2mm,enlarge y limits=.12]
\addplot[fill=blue,draw=none] coordinates {(7.00,Origine) (33.56,50 mm) (33.75,48 mm) (33.12,45 mm) (29.75,41 mm) (25.00,41 couchée) (20.00,41 boîte)};
\end{axis}
\end{tikzpicture}
\end{minipage}\hfill
\begin{minipage}[t]{0.47\textwidth}
\centering
\textbf{Moyenne des cinq meilleurs RSSI}\par\smallskip
\begin{tikzpicture}
\begin{axis}[
  width=.95\linewidth,height=58mm,
  xmin=-85,xmax=-38,
  symbolic y coords={Origine,50 mm,48 mm,45 mm,41 mm,41 couchée,41 boîte},
  ytick=data,y dir=reverse,
  xlabel={RSSI (dBm) \quad meilleur $\rightarrow$},
  nodes near coords,nodes near coords align={horizontal},
  every node near coord/.append style={font=\scriptsize},
  tick label style={font=\scriptsize},label style={font=\scriptsize},
  axis line style={draw=line},grid=major,grid style={draw=line!70},
  enlarge y limits=.12]
\addplot[only marks,mark=*,mark size=2.4pt,color=green] coordinates {(-78.43,Origine) (-44.24,50 mm) (-54.10,48 mm) (-45.92,45 mm) (-44.30,41 mm) (-54.45,41 couchée) (-61.50,41 boîte)};
\end{axis}
\end{tikzpicture}
\end{minipage}

\vspace{3mm}
\begin{tabularx}{\textwidth}{>{\bfseries}l C{13mm} C{24mm} C{23mm} C{20mm} Y}
\toprule
Configuration & \(n\) & Réseaux \(\mu\pm s\) & Top 5 \(\mu\pm s\) & Plus fort & Lecture \\
\midrule
Origine & 6 & 7,0 $\pm$ 0,6 & $-78,4\pm0,6$ & $-77,8$ & Référence très faible \\
\rowcolor{green!7} 50 mm verticale & 9 & 33,6 $\pm$ 3,5 & $-44,2\pm0,8$ & $-43,3$ & \textbf{Meilleur ensemble} \\
48 mm verticale & 4 & 33,8 $\pm$ 1,0 & $-54,1\pm2,1$ & $-53,0$ & Détection élevée, signal proche atypiquement faible \\
45 mm verticale & 8 & 33,1 $\pm$ 1,8 & $-45,9\pm0,4$ & $-45,1$ & \textbf{Meilleur compromis compact} \\
41 mm verticale & 4 & 29,8 $\pm$ 1,3 & $-44,3\pm0,6$ & $-43,5$ & Excellent proche, recul en couverture \\
41 mm couchée & 4 & 25,0 $\pm$ 1,4 & $-54,5\pm3,8$ & $-54,0$ & Orientation pénalisante \\
41 mm couchée, boîte & 4 & 20,0 $\pm$ 0,8 & $-61,5\pm0,4$ & $-60,3$ & Intégration très pénalisante \\
\bottomrule
\end{tabularx}

\vspace{4mm}
\begin{decisionbox}
\textbf{Interprétation.} Le nombre de réseaux seul placerait la 48 mm légèrement devant la 50 mm (0,2 réseau, non significatif au regard de la variabilité). Les signaux dominants donnent toutefois un avantage de \textbf{9,9 dB} à la 50 mm. Le choix doit donc reposer sur plusieurs indicateurs, pas sur le seul compteur de réseaux.
\end{decisionbox}
\newpage

% --- Page 4 ---------------------------------------------------------------
\sectiontitle{3. Comparaison sur des points d'accès repères}{La 50 mm conserve son avantage sur les liens proches comme sur les liens plus difficiles}

\begin{minipage}[t]{0.58\textwidth}
\centering
\textbf{RSSI moyen lorsque le repère est détecté}\par
\begin{tikzpicture}
\begin{axis}[
  width=.96\linewidth,height=76mm,
  ybar,bar width=2.6mm,
  ymin=-100,ymax=-35,
  ylabel={RSSI moyen (dBm)},
  symbolic x coords={Dev11,Gateway,Dev6,ZyXEL,Sauter},xtick=data,
  xticklabels={Devices c.11,Gateway c.1,Devices c.6,ZyXEL c.5,Sauter c.3},
  x tick label style={font=\scriptsize,rotate=24,anchor=east},
  tick label style={font=\scriptsize},label style={font=\scriptsize},
  grid=major,grid style={draw=line!70},axis line style={draw=line},
  legend style={font=\scriptsize,at={(0.5,1.03)},anchor=south,legend columns=4,draw=none}]
\addplot[fill=navy,draw=none] coordinates {(Dev11,-44.6) (Gateway,-59.1) (Dev6,-63.6) (ZyXEL,-68.5) (Sauter,-71.5)};
\addplot[fill=cyan,draw=none] coordinates {(Dev11,-54.2) (Gateway,-65.0) (Dev6,-65.2) (ZyXEL,-68.2) (Sauter,-74.3)};
\addplot[fill=green,draw=none] coordinates {(Dev11,-46.1) (Gateway,-62.8) (Dev6,-64.4) (ZyXEL,-71.6) (Sauter,-74.4)};
\addplot[fill=orange,draw=none] coordinates {(Dev11,-44.5) (Gateway,-63.0) (Dev6,-65.5) (ZyXEL,-73.5) (Sauter,-74.0)};
\legend{50 mm,48 mm,45 mm,41 mm}
\end{axis}
\end{tikzpicture}
\end{minipage}\hfill
\begin{minipage}[t]{0.39\textwidth}
\textbf{Ce que montrent les repères}
\begin{itemize}
  \item Sur \textit{Devices} canal 11, la 50 mm et la 41 mm sont à égalité pratique ; la 45 mm suit à 1,5 dB.
  \item Sur \textit{Gateway}, la 50 mm gagne 3,6 dB face à la 45 mm et 3,9 dB face à la 41 mm.
  \item Sur \textit{ZyXEL}, la 50 mm est détectée 8 fois sur 9 ; la 45 mm seulement 5 fois sur 8, la 41 mm 2 fois sur 4.
  \item La 48 mm reçoit bien certains liens distants, mais perd près de 10 dB sur le point d'accès dominant du canal 11. Ce comportement mérite un nouveau test.
\end{itemize}
\end{minipage}

\vspace{4mm}
\begin{tabularx}{\textwidth}{>{\bfseries}l C{21mm} C{21mm} C{21mm} C{21mm} Y}
\toprule
Configuration & Devices c.11 & Gateway c.1 & Devices c.6 & ZyXEL c.5 & Détection ZyXEL / Sauter \\
\midrule
50 mm & $-44,6$ & $-59,1$ & $-63,6$ & $-68,5$ & 8/9 \quad / \quad 8/9 \\
48 mm & $-54,2$ & $-65,0$ & $-65,2$ & $-68,2$ & 4/4 \quad / \quad 3/4 \\
45 mm & $-46,1$ & $-62,8$ & $-64,4$ & $-71,6$ & 5/8 \quad / \quad 5/8 \\
41 mm & $-44,5$ & $-63,0$ & $-65,5$ & $-73,5$ & 2/4 \quad / \quad 4/4 \\
\bottomrule
\end{tabularx}
{\footnotesize\color{muted}Valeurs en dBm. La moyenne est calculée uniquement lors des détections ; le taux de détection complète donc indispensablement la lecture.}

\vspace{5mm}
\begin{tcolorbox}[colback=paper,colframe=line,boxrule=.5pt,arc=2mm]
\textbf{Gain face à l'antenne d'origine.} Pour la 50 mm, le top 5 progresse de \textbf{34,2 dB}, \textit{Devices} canal 11 de \textbf{34,1 dB} et la passerelle de \textbf{25,6 dB}. Le nombre moyen de réseaux passe de 7,0 à 33,6 (\textbf{$\times$4,8}). L'amélioration est beaucoup plus grande que la dispersion entre scans et ne peut raisonnablement être attribuée au seul bruit de mesure.
\end{tcolorbox}

\begin{warningbox}
\textbf{Point de vigilance temporel.} Sur la série 50 mm, le nombre de réseaux diminue d'environ 0,9 par scan, alors que le top 5 s'améliore légèrement (+0,23 dB par scan). Cela suggère surtout une variation des réseaux faibles présents, et renforce l'usage des repères et du top 5 pour classer les antennes.
\end{warningbox}
\newpage

% --- Page 5 ---------------------------------------------------------------
\sectiontitle{4. Tendances de géométrie et d'intégration}{La longueur n'explique pas tout ; l'orientation et le boîtier dominent la performance finale}

\begin{minipage}[t]{0.49\textwidth}
\textbf{Longueur, antenne verticale}
\begin{tikzpicture}
\begin{axis}[
  width=.95\linewidth,height=58mm,
  xmin=40,xmax=51,xtick={41,45,48,50},
  xlabel={longueur totale (mm)},ylabel={top 5 RSSI (dBm)},
  ymin=-58,ymax=-40,
  grid=major,grid style={draw=line!70},axis line style={draw=line},
  tick label style={font=\scriptsize},label style={font=\scriptsize}]
\addplot[color=blue,very thick,mark=*,mark options={fill=blue}] coordinates {(41,-44.30) (45,-45.92) (48,-54.10) (50,-44.24)};
\end{axis}
\end{tikzpicture}
\end{minipage}\hfill
\begin{minipage}[t]{0.49\textwidth}
\textbf{Intégration de la 41 mm}
\begin{tikzpicture}
\begin{axis}[
  width=.95\linewidth,height=58mm,
  ybar,bar width=11mm,ymin=-66,ymax=-40,
  symbolic x coords={Verticale,Couchée,Boîte},xtick=data,
  xticklabels={Verticale,Couchée,Couchée + boîte},
  ylabel={top 5 RSSI (dBm)},
  nodes near coords,every node near coord/.append style={font=\scriptsize},
  grid=major,grid style={draw=line!70},axis line style={draw=line},
  tick label style={font=\scriptsize},label style={font=\scriptsize}]
\addplot[fill=orange,draw=none] coordinates {(Verticale,-44.30) (Couchée,-54.45) (Boîte,-61.50)};
\end{axis}
\end{tikzpicture}
\end{minipage}

\begin{tcolorbox}[colback=blue!5,colframe=blue!35,boxrule=.5pt,arc=2mm]
\textbf{Pas de tendance monotone avec la longueur.} Les résultats 41, 45 et 50 mm sont proches sur le signal dominant, alors que la 48 mm présente un creux marqué. Cela indique une interaction entre longueur électrique, boucle, plan de masse, routage et environnement proche. Une simple interpolation géométrique serait donc risquée.
\end{tcolorbox}

\vspace{2mm}
\textbf{Décomposition de la pénalité d'intégration sur la 41 mm}\par\smallskip
\begin{tabularx}{\textwidth}{>{\bfseries}l C{25mm} C{25mm} C{25mm} Y}
\toprule
Transition & Réseaux/scan & Top 5 & Gateway & Interprétation \\
\midrule
Verticale $\rightarrow$ couchée & $-4,8$ & $-10,2$ dB & $-2,2$ dB & Forte perte directionnelle / couplage avec le support \\
Couchée $\rightarrow$ boîte fermée & $-5,0$ & $-7,1$ dB & $-13,3$ dB & Désaccord et absorption liés à l'intégration \\
Verticale $\rightarrow$ produit fermé & $-9,8$ & $-17,2$ dB & $-15,5$ dB & La mécanique annule une part majeure du gain antenne \\
\bottomrule
\end{tabularx}

\vspace{5mm}
\begin{warningbox}
\textbf{Implication produit.} Optimiser l'antenne à l'air libre ne suffit pas. La position, la distance à la batterie et au PCB, le plastique, les fils ainsi que le poignet peuvent déplacer la résonance et modifier le diagramme de rayonnement. Une marge de 2 ou 3 dB entre candidates devient secondaire face à une pénalité d'intégration mesurée de 17 dB.
\end{warningbox}

\vspace{3mm}
\textbf{Lecture de la stabilité}
\begin{itemize}
  \item Les séries 45 mm, 41 mm verticale et 50 mm ont un écart-type du top 5 inférieur à 1 dB : leur réception dominante est répétable.
  \item La 48 mm (2,1 dB) et surtout la 41 mm couchée (3,8 dB) varient davantage ; ces configurations sont plus sensibles à l'environnement ou à l'orientation.
  \item La boîte fermée est stable (0,4 dB) mais stable à un niveau nettement dégradé : la répétabilité ne compense pas la perte absolue.
\end{itemize}
\newpage

% --- Page 6 ---------------------------------------------------------------
\sectiontitle{5. Décision et plan de validation}{Choisir la 50 mm pour le prochain prototype, avec une porte de sortie 45 mm}

\textbf{Classement argumenté des géométries verticales}\par\smallskip
\begin{tabularx}{\textwidth}{C{11mm} >{\bfseries}p{28mm} C{22mm} C{22mm} Y}
\toprule
Rang & Candidate & Signal dominant & Couverture & Justification \\
\midrule
\rowcolor{green!8}\textbf{1} & 50 mm & Excellent & Excellente & Meilleure combinaison top 5, passerelle, réseaux distants et répétabilité ; série la plus fournie (9 scans). \\
\textbf{2} & 45 mm & Très bon & Excellente & Seulement 1,7 dB derrière sur le top 5 ; compacte et très stable. Meilleur compromis mécanique. \\
\textbf{3} & 41 mm & Excellent proche & Bonne & Niveau proche au meilleur, mais 3,8 réseaux de moins et réception distante plus faible ; intégration mesurée défavorable. \\
\textbf{4} & 48 mm & Moyen / atypique & Excellente & Nombre de réseaux élevé, mais perte de 9,9 dB sur le top 5 face à la 50 mm et seulement 4 scans. À recontrôler. \\
\bottomrule
\end{tabularx}

\vspace{4mm}
\begin{decisionbox}
\textbf{Recommandation.} Réaliser le prochain prototype avec la \textbf{50 mm verticale}. Si cette géométrie est incompatible avec le volume disponible, retenir la \textbf{45 mm} : la réduction d'encombrement coûte peu sur le lien dominant, avec une perte mesurée plus visible sur les liens distants. Ne pas figer la production avant un essai comparatif 50/45 dans le produit réellement fermé et porté.
\end{decisionbox}

\vspace{4mm}
\textbf{Validation minimale avant gel de conception}
\begin{enumerate}[leftmargin=7mm,itemsep=3pt,topsep=2pt]
  \item \textbf{A/B 50 mm vs 45 mm :} au moins 20 scans alternés par configuration, même emplacement, ordre randomisé pour neutraliser la dérive temporelle.
  \item \textbf{Configurations réelles :} boîtier fermé, batterie présente, bracelet au poignet ; tester au minimum quatre orientations du corps et deux poignets/utilisateurs.
  \item \textbf{Mesure applicative :} enregistrer RSSI du point d'accès cible, taux de paquets ESP-NOW perdus, temps de reconnexion et latence d'acquittement, pas seulement le nombre de SSID.
  \item \textbf{Cas limites :} station dans une autre pièce, porte fermée, mouvement du bras, moteur vibrant et batterie faible.
  \item \textbf{Critère proposé :} zéro perte de session critique ; RSSI cible idéalement supérieur à \(-70\) dBm, marge jusqu'à \(-80\) dBm ; taux de livraison ESP-NOW supérieur à 99\% pendant la fenêtre d'alarme.
\end{enumerate}

\begin{warningbox}
\textbf{Mesure RF recommandée si disponible.} Un VNA permettrait de vérifier le coefficient de réflexion autour de 2,4 GHz dans chaque état mécanique. À défaut, conserver le test applicatif fermé et porté comme arbitre final : c'est lui qui reflète le fonctionnement réel du bracelet.
\end{warningbox}

\vspace{3mm}
\textbf{Conclusion}

L'antenne modifiée apporte une amélioration majeure face à l'origine. Parmi les variantes mesurées, la \textbf{50 mm} est la candidate la mieux étayée pour maximiser la marge radio ; la \textbf{45 mm} est une alternative compacte crédible. Le principal risque n'est plus la différence de quelques millimètres, mais l'intégration mécanique : la mesure de la 41 mm montre qu'une mauvaise orientation et le boîtier peuvent coûter plus de 17 dB. La prochaine décision doit donc être prise sur un A/B 50/45, produit fermé et porté, avec des paquets applicatifs réels.

\vfill
\begin{tcolorbox}[colback=paper,colframe=line,boxrule=.5pt,arc=2mm]
{\footnotesize\color{muted}\textbf{Traçabilité.} Calculs effectués à partir des 39 blocs de scans du fichier brut \texttt{app mobile/mesures.txt}. Moyennes et écarts-types sont calculés entre scans ; les valeurs de points d'accès utilisent le meilleur RSSI du couple SSID/canal dans chaque scan. Aucun lissage ni exclusion de scan n'a été appliqué.}
\end{tcolorbox}

\end{document}

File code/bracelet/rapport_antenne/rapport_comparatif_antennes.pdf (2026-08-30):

RAPPORT D’ESSAIS • WI-FI 2,4 GHz

# Comparaison des antennes du bracelet

Analyse quantitative, tendances et recommandation de conception

Décision sur les données actuelles : antenne 50 mm, verticale
Elle offre le meilleur ensemble de résultats : niveau des signaux dominants, réception des points d’accès éloignés et régularité. La 45 mm est le meilleur compromis si l’encombrement impose une réduction. La décision reste à confirmer boîtier fermé et au poignet, conditions non mesurées pour ces deux candidates.

39

scans analysés

1 043

détections Wi-Fi

+34,2 dB

gain 50 mm vs origine
(moyenne du top 5)

Lecture en 30 secondes

— 50 mm : 33,6 réseaux par scan et top 5 à −44, 2 dBm ; meilleur choix radio global.
— 45 mm : 33,1 réseaux et top 5 à −45, 9 dBm ; seulement 1,7 dB derrière sur les signaux dominants, mais 3,6 dB derrière sur la passerelle de référence.
— 41 mm verticale : très bon signal proche, mais moins de réseaux (29,8) et réception distante moins convaincante.
— Intégration : la 41 mm perd 10,2 dB couchée, puis encore 7,1 dB avec le boîtier fermé sur l’indicateur top 5.

Source : app mobile/mesures.txt • Conditions déclarées identiques sauf mention contraire • RSSI en dBm (moins négatif = meilleur)

BRACELET • ÉVALUATION RF | 04 août 2026

# 1. Protocole et méthode

Une comparaison centrée sur la qualité de réception et la robustesse de la décision

Configurations étudiées
— antenne d’origine : 6 scans ;
— fil de section 1 mm, boucle 18 mm : longueurs 50, 48, 45 et 41 mm, en position verticale ;
— antenne 41 mm couchée ;
— antenne 41 mm couchée, boîtier fermé.

Échantillonnage

— 39 scans au total, groupes de 4 à 9 scans ;
— environnement et conditions annoncés identiques ;
— chaque ligne fournit SSID, canal et RSSI ;
— aucune adresse BSSID ni mesure d’émission n’est fournie.

Indicateurs retenus

Indicateur

Rôle dans la décision | Précaution d’interprétation

Réseaux visibles

Couverture et capacité à détecter des signaux faibles | Dépend de l’occupation ra- dio instantanée

Moyenne du top 5

Qualité des cinq meilleures réceptions de chaque scan | Plus robuste que la moyenne de toutes les lignes

Points d’accès repères

Comparaison de liens identifiables par SSID et canal | Un SSID peut regrouper plu- sieurs BSSID

Écart-type entre
scans
Répétabilité à court terme | Les groupes n’ont pas tous la même taille

Taux de détection

Robustesse sur les réseaux faibles | Sensible au seuil et aux trames diffusées

Pourquoi la moyenne de tous les RSSI serait trompeuse. Une meilleure antenne détecte davantage de réseaux faibles ; ces nouvelles valeurs très négatives peuvent dégrader sa moyenne brute. Le rapport privilégie donc le top 5, les points d’accès repères et le nombre de réseaux.

Limites à conserver dans la décision

— Il s’agit de scans en réception. Ils ne mesurent ni débit, ni pertes ESP-NOW, ni latence, ni puissance effectivement rayonnée.

— L’absence de BSSID empêche d’identifier sans ambiguïté les différents points d’accès portant le même SSID.

— Une seule géométrie (41 mm) est mesurée couchée et boîtier fermé ; l’effet du boîtier ne peut pas être transposé exactement aux autres longueurs.

— Le corps, la batterie, le mouvement et l’orientation du poignet peuvent désaccorder l’antenne. La recommandation est donc une sélection pour le prochain prototype, pas une validation RF finale.

Convention : un RSSI plus proche de 0 est meilleur. Un écart de 3 dB correspond approximativement à un facteur 2 de puissance reçue ; cette conversion reste indicative car les RSSI embarqués ne sont pas des mesures de laboratoire calibrées.

Analyse des scans Wi-Fi 2,4 GHz | 2/6

# 2. Résultats globaux

Les trois meilleures géométries détectent environ 33 réseaux, mais leur qualité de signal diffère

Réseaux visibles par scan

0 | 10 | 20 | 30 | 40

Origine

50 mm

48 mm

45 mm

41 mm

41 couchée

41 boîte

7

33.56

33.75

33.12

29.75

25

20

moyenne

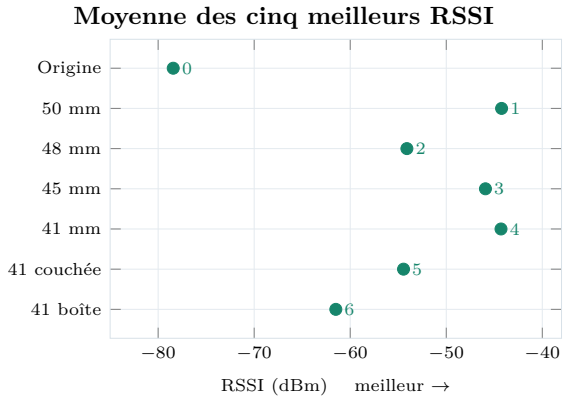
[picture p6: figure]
Moyenne des cinq meilleurs RSSI; Origine; 41 couchée; 41 boîte; RSSI (dBm); meilleur →

Configuration | n | Réseaux µ ± s | Top 5 µ ± s | Plus fort | Lecture
Origine | 6 | 7,0 ± 0,6 | −78, 4 ± 0, 6 | −77, 8 | Référence très faible
50 mm verticale | 9 | 33,6 ± 3,5 | −44, 2 ± 0, 8 | −43, 3 | Meilleur ensemble
48 mm verticale | 4 | 33,8 ± 1,0 | −54, 1 ± 2, 1 | −53, 0 | Détection élevée, signal proche atypiquement faible
45 mm verticale | 8 | 33,1 ± 1,8 | −45, 9 ± 0, 4 | −45, 1 | Meilleur compromis compact
41 mm verticale | 4 | 29,8 ± 1,3 | −44, 3 ± 0, 6 | −43, 5 | Excellent proche, recul en couverture
41 mm couchée | 4 | 25,0 ± 1,4 | −54, 5 ± 3, 8 | −54, 0 | Orientation pénalisante
41 mm couchée, boîte | 4 | 20,0 ± 0,8 | −61, 5 ± 0, 4 | −60, 3 | Intégration très pénalisante

Interprétation. Le nombre de réseaux seul placerait la 48 mm légèrement devant la 50 mm (0,2 réseau, non significatif au regard de la variabilité). Les signaux dominants donnent toutefois un avantage de 9,9 dB à la 50 mm. Le choix doit donc reposer sur plusieurs indicateurs, pas sur le seul compteur de réseaux.

# 3. Comparaison sur des points d’accès repères

La 50 mm conserve son avantage sur les liens proches comme sur les liens plus difficiles

RSSI moyen lorsque le repère est détecté

Devices c.11

Gateway c.1
Devices c.6

ZyXEL c.5
Sauter c.3

−100

−80

−60

−40

RSSI moyen (dBm)

50 mm | 48 mm | 45 mm | 41 mm

Ce que montrent les repères
— Sur Devices canal 11, la 50 mm et la 41 mm sont à égalité pratique ; la 45 mm suit à 1,5 dB.
— Sur Gateway, la 50 mm gagne 3,6 dB face à la 45 mm et 3,9 dB face à la 41 mm.
— Sur ZyXEL, la 50 mm est détectée 8 fois sur 9 ; la 45 mm seulement 5 fois sur 8, la 41 mm 2 fois sur 4.

— La 48 mm reçoit bien certains liens distants, mais perd près de 10 dB sur le point d’accès dominant du canal 11. Ce comportement mérite un nouveau test.

Configuration | Devices c.11 | Gateway c.1 | Devices c.6 | ZyXEL c.5 | Détection ZyXEL / Sauter
50 mm | −44, 6 | −59, 1 | −63, 6 | −68, 5 | 8/9 | / | 8/9
48 mm | −54, 2 | −65, 0 | −65, 2 | −68, 2 | 4/4 | / | 3/4
45 mm | −46, 1 | −62, 8 | −64, 4 | −71, 6 | 5/8 | / | 5/8
41 mm | −44, 5 | −63, 0 | −65, 5 | −73, 5 | 2/4 | / | 4/4

Valeurs en dBm. La moyenne est calculée uniquement lors des détections ; le taux de détection complète donc indispensablement la lecture.

Gain face à l’antenne d’origine. Pour la 50 mm, le top 5 progresse de 34,2 dB, Devices canal 11 de 34,1 dB et la passerelle de 25,6 dB. Le nombre moyen de réseaux passe de 7,0 à 33,6 (×4,8). L’amélioration est beaucoup plus grande que la dispersion entre scans et ne peut raisonnablement être attribuée au seul bruit de mesure.

Point de vigilance temporel. Sur la série 50 mm, le nombre de réseaux diminue d’environ 0,9 par scan, alors que le top 5 s’améliore légèrement (+0,23 dB par scan). Cela suggère surtout une variation des réseaux faibles présents, et renforce l’usage des repères et du top 5 pour classer les antennes.

# 4. Tendances de géométrie et d’intégration

La longueur n’explique pas tout ; l’orientation et le boîtier dominent la performance finale

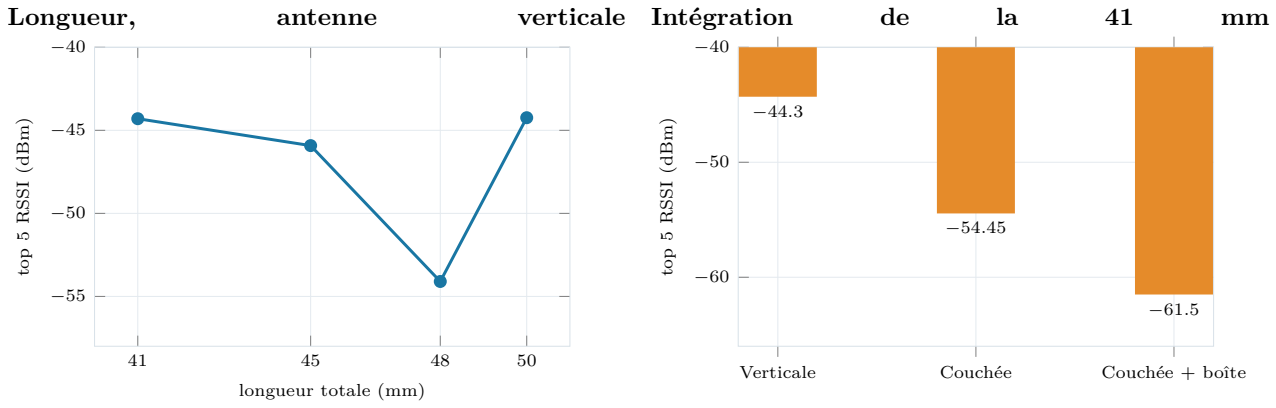
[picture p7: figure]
Longueur,; antenne; verticale; longueur totale (mm); top 5 RSSI (dBm); Intégration; Verticale; Couchée; Couchée + boîte

Pas de tendance monotone avec la longueur. Les résultats 41, 45 et 50 mm sont proches sur le signal dominant, alors que la 48 mm présente un creux marqué. Cela indique une interaction entre longueur électrique, boucle, plan de masse, routage et environnement proche. Une simple interpolation géométrique serait donc risquée.

Décomposition de la pénalité d’intégration sur la 41 mm

Transition | Réseaux/scan | Top 5 | Gateway | Interprétation
Verticale → couchée | −4, 8 | −10, 2 dB | −2, 2 dB | Forte perte directionnelle / couplage avec le support
Couchée → boîte fermée | −5, 0 | −7, 1 dB | −13, 3 dB | Désaccord et absorption liés à l’intégration
Verticale → produit fermé | −9, 8 | −17, 2 dB | −15, 5 dB | La mécanique annule une part majeure du gain antenne

Implication produit. Optimiser l’antenne à l’air libre ne suffit pas. La position, la distance à la batterie et au PCB, le plastique, les fils ainsi que le poignet peuvent déplacer la résonance et modifier le diagramme de rayonnement. Une marge de 2 ou 3 dB entre candidates devient secondaire face à une pénalité d’intégration mesurée de 17 dB.

Lecture de la stabilité

— Les séries 45 mm, 41 mm verticale et 50 mm ont un écart-type du top 5 inférieur à 1 dB : leur réception dominante est répétable.

— La 48 mm (2,1 dB) et surtout la 41 mm couchée (3,8 dB) varient davantage ; ces configurations sont plus sensibles à l’environnement ou à l’orientation.

— La boîte fermée est stable (0,4 dB) mais stable à un niveau nettement dégradé : la répétabilité ne compense pas la perte absolue.

# 5. Décision et plan de validation

Choisir la 50 mm pour le prochain prototype, avec une porte de sortie 45 mm

Classement argumenté des géométries verticales

Rang | Candidate | Signal dominant | Couverture | Justification
1 | 50 mm | Excellent | Excellente | Meilleure combinaison top 5, passerelle, réseaux distants et répétabilité ; série la plus fournie (9 scans).
2 | 45 mm | Très bon | Excellente | Seulement 1,7 dB derrière sur le top 5 ; compacte et très stable. Meilleur compromis mécanique.
3 | 41 mm | Excellent proche | Bonne | Niveau proche au meilleur, mais 3,8 réseaux de moins et réception distante plus faible ; intégration mesurée défavorable.
4 | 48 mm | Moyen / atypique | Excellente | Nombre de réseaux élevé, mais perte de 9,9 dB sur le top 5 face à la 50 mm et seulement 4 scans. À recontrôler.

Recommandation. Réaliser le prochain prototype avec la 50 mm verticale. Si cette géométrie est incompatible avec le volume disponible, retenir la 45 mm : la réduction d’encombrement coûte peu sur le lien dominant, avec une perte mesurée plus visible sur les liens distants. Ne pas figer la production avant un essai comparatif 50/45 dans le produit réellement fermé et porté.

Validation minimale avant gel de conception

1. A/B 50 mm vs 45 mm : au moins 20 scans alternés par configuration, même emplacement, ordre randomisé pour neutraliser la dérive temporelle.
2. Configurations réelles : boîtier fermé, batterie présente, bracelet au poignet ; tester au minimum quatre orientations du corps et deux poignets/utilisateurs.
3. Mesure applicative : enregistrer RSSI du point d’accès cible, taux de paquets ESP-NOW perdus, temps de reconnexion et latence d’acquittement, pas seulement le nombre de SSID.
4. Cas limites : station dans une autre pièce, porte fermée, mouvement du bras, moteur vibrant et batterie faible.
5. Critère proposé : zéro perte de session critique ; RSSI cible idéalement supérieur à −70 dBm, marge jusqu’à −80 dBm ; taux de livraison ESP-NOW supérieur à 99% pendant la fenêtre d’alarme.

Mesure RF recommandée si disponible. Un VNA permettrait de vérifier le coefficient de réflexion autour de 2,4 GHz dans chaque état mécanique. À défaut, conserver le test applicatif fermé et porté comme arbitre final : c’est lui qui reflète le fonctionnement réel du bracelet.

Conclusion

L’antenne modifiée apporte une amélioration majeure face à l’origine. Parmi les variantes mesurées, la 50 mm est la candidate la mieux étayée pour maximiser la marge radio ; la 45 mm est une alternative compacte crédible. Le principal risque n’est plus la différence de quelques millimètres, mais l’intégration mécanique : la mesure de la 41 mm montre qu’une mauvaise orientation et le boîtier peuvent coûter plus de 17 dB. La prochaine décision doit donc être prise sur un A/B 50/45, produit fermé et porté, avec des paquets applicatifs réels.

Traçabilité. Calculs effectués à partir des 39 blocs de scans du fichier brut app mobile/mesures.txt. Moyennes et écarts-types sont calculés entre scans ; les valeurs de points d’accès utilisent le meilleur RSSI du couple SSID/canal dans chaque scan. Aucun

lissage ni exclusion de scan n’a été appliqué.

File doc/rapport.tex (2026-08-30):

\documentclass[11pt,a4paper]{article}

\usepackage[utf8]{inputenc}
\usepackage[T1]{fontenc}
\usepackage[french]{babel}
\usepackage{geometry}
\usepackage{graphicx}
\usepackage{hyperref}
\usepackage{xcolor}
\usepackage{array}
\usepackage{booktabs}
\usepackage{longtable}
\usepackage{enumitem}
\usepackage{float}

\geometry{margin=2.4cm}
\hypersetup{
  colorlinks=true,
  linkcolor=blue!45!black,
  urlcolor=blue!45!black
}
\setlist[itemize]{noitemsep, topsep=0.25em}
\setlist[enumerate]{noitemsep, topsep=0.25em}
\graphicspath{
  {../code/app mobile/UML/}
  {../code/boite hp/UML/}
  {../code/bracelet/UML/}
}

\title{\textbf{Starter}\\Rapport d'architecture et de compréhension du code}
\author{Projet personnel de réveil actif}
\date{\today}

\begin{document}

\maketitle
\tableofcontents
\newpage

\section{Objectif du projet}

Starter est un système de réveil personnel conçu pour rendre le retour au sommeil difficile. Le principe produit est volontairement simple: l'utilisateur prépare le réveil le soir, puis le système impose une activité physique minimale pendant les quinze premières minutes après l'heure configurée.

Le projet v1 est composé de trois parties actives:

\begin{itemize}
  \item une station de chevet, située dans \texttt{code/boite hp}, qui joue le rôle d'autorité centrale de l'alarme;
  \item un bracelet dédié, situé dans \texttt{code/bracelet}, qui mesure l'activité et la transmet à la station;
  \item une PWA mobile Vue/Vite, située dans \texttt{code/app mobile}, qui configure l'alarme et la musique via Supabase.
\end{itemize}

La règle centrale est que la station décide quand l'alarme démarre, quand le son est audible, et quand le cycle est terminé. La PWA ne déclenche pas l'alarme directement. Le bracelet ne stoppe pas l'alarme: il fournit uniquement une mesure d'activité que la station interprète.

\section{Vue d'ensemble de l'architecture}

Le flux de configuration v1 est:

\begin{center}
\texttt{PWA -> Supabase -> station}
\end{center}

Le flux d'activité est:

\begin{center}
\texttt{bracelet -> ESP-NOW -> station}
\end{center}

Supabase est utilisé pour stocker la musique, la sélection audio, la prochaine alarme et les états visibles par l'application. ESP-NOW est utilisé entre le bracelet et la station afin d'éviter un comportement WiFi lourd côté bracelet. Le transport ESP-NOW reste une hypothèse à valider physiquement sur la distance réelle d'utilisation.

\subsection{Règles produit non négociables}

\begin{itemize}
  \item La station reste l'autorité centrale.
  \item Supabase est utilisé pour la configuration et les musiques en v1.
  \item Le bracelet communique avec la station par ESP-NOW en v1.
  \item Il n'existe pas de bouton normal stop ou snooze.
  \item Le son est contrôlé par l'activité du bracelet pendant une fenêtre fixe de dix minutes.
  \item Une panne technique bloquante doit placer le système dans un état de défaut visible.
  \item Un échec de streaming Supabase ne doit pas annuler le réveil: la station utilise un son local de secours.
\end{itemize}

\section{PWA mobile}

La PWA est l'interface utilisateur. Elle permet d'ajouter de la musique, de sélectionner une piste ou le fallback local, de configurer une alarme et de consulter l'état de la station et du bracelet.

\begin{center}
  \centering
  
  \textbf{Diagramme: cas d'utilisation de la PWA}
\end{center}

\subsection{Responsabilités}

\begin{itemize}
  \item Uploader des fichiers audio vers le bucket Supabase \texttt{wake-up-music}.
  \item Créer les métadonnées dans \texttt{music\_tracks}.
  \item Écrire la configuration dans \texttt{alarm\_plan}.
  \item Écrire la sélection audio dans \texttt{alarm\_audio\_selection}.
  \item Lire \texttt{station\_status} et \texttt{bracelet\_status}.
  \item Afficher les défauts sans devenir l'autorité d'alarme.
\end{itemize}

Le code actuel utilise Vue 3, Vite, TypeScript, \texttt{@supabase/supabase-js} et \texttt{lucide-vue-next}. La configuration Supabase côté PWA passe par \texttt{VITE\_SUPABASE\_URL} et \texttt{VITE\_SUPABASE\_ANON\_KEY}. Cette clé anon est acceptable pour le prototype personnel, mais ce n'est pas un modèle de sécurité production.

\subsection{Fenêtre de sélection d'alarme}

La PWA propose des créneaux dans les douze prochaines heures, par pas de cinq minutes. Lorsqu'une alarme est sauvegardée, l'application incrémente la révision afin que la station puisse détecter une nouvelle configuration.

\section{Backend Supabase}

Supabase est le backend v1 pour les fichiers audio, la configuration de l'alarme et la publication des états. Le schéma SQL concret se trouve dans \texttt{database/supabase/v1\_schema.sql}.

\begin{longtable}{>{\ttfamily}p{0.28\linewidth}p{0.64\linewidth}}
\toprule
\normalfont Table & Rôle \\
\midrule
\endhead
music\_tracks & Bibliothèque des fichiers audio uploadés, avec titre, chemin de stockage, URL publique et disponibilité. \\
alarm\_plan & Ligne unique \texttt{main} contenant activation, date, heure locale, timezone et révision. \\
alarm\_audio\_selection & Ligne unique \texttt{main} contenant la source audio, la piste sélectionnée et le volume. \\
station\_status & État publié par la station: état courant, défaut, message, révision active, tension batterie. \\
bracelet\_status & État du bracelet vu par la station: état, défaut, message, tension batterie, dernière réception. \\
\bottomrule
\end{longtable}

Le bucket Supabase \texttt{wake-up-music} accepte les fichiers audio MPEG, WAV, OGG et MP4 audio jusqu'à 50 MiB. Les politiques RLS actuelles autorisent le client anon à lire et écrire les tables v1 et le bucket. Cette décision est explicitement limitée au prototype personnel.

\section{Station de chevet}

La station est un firmware PlatformIO Arduino pour ESP32. Elle synchronise l'heure, charge la configuration depuis Supabase, reçoit la télémétrie du bracelet, joue la musique sélectionnée et applique la logique d'alarme.

\begin{center}
  \centering
  
  \textbf{Diagramme: flux de communication de la station}
\end{center}

\subsection{Responsabilités}

\begin{itemize}
  \item Connexion WiFi et synchronisation NTP.
  \item Lecture de \texttt{alarm\_plan}, \texttt{alarm\_audio\_selection} et \texttt{music\_tracks}.
  \item Cache local de la dernière configuration valide.
  \item Streaming de l'URL publique Supabase via la chaîne audio PCM5102A/PAM8403.
  \item Fallback local généré si la musique Supabase échoue.
  \item Réception des paquets \texttt{bracelet\_status} ESP-NOW.
  \item Envoi optionnel de \texttt{station\_control} au bracelet.
  \item Publication de \texttt{station\_status} et \texttt{bracelet\_status}.
\end{itemize}

\subsection{Machine d'état}

\begin{center}
  \centering
  
  \textbf{Diagramme: machine d'état v1 de la station}
\end{center}

Les états exposés par la station sont \texttt{idle}, \texttt{armed}, \texttt{ringing}, \texttt{validating\_activity}, \texttt{stopped} et \texttt{fault}. Le passage en \texttt{ringing} se produit lorsque l'heure locale configurée est atteinte et que les prérequis sont valides. Le passage en \texttt{validating\_activity} signifie que la station a confirmé un événement de mouvement encore valable; elle coupe alors la sortie audio via \texttt{XSMT} pour la partie restante de l'intervalle de dix secondes, mais le cycle d'alarme continue.

Une perte ESP-NOW supérieure à trois secondes publie \texttt{bracelet\_missing}. Elle n'annule plus une sourdine déjà accordée. À son expiration, la station demande une vibration identifiée et attend que le bracelet confirme le démarrage réel du moteur avant de laisser trois secondes à l'utilisateur. Sans confirmation après trois secondes, la musique reprend afin qu'une déconnexion ne puisse pas neutraliser le réveil.

La fenêtre d'activité dure dix minutes à partir de l'heure configurée. À la fin de cette fenêtre, la station arrête le son et marque la révision comme terminée. Il n'y a pas de transition stop ou snooze normale depuis \texttt{ringing} ou \texttt{validating\_activity}.

\subsection{Défauts et fallback}

Avant l'alarme, les défauts bloquants incluent l'absence d'heure valide, l'absence de configuration valide, un bracelet manquant ou en défaut, une batterie bracelet trop basse et un problème audio. Dans ces cas, la station doit publier un défaut visible.

L'échec du streaming musical au moment du réveil n'est pas bloquant pour le réveil lui-même. La station bascule sur un son local généré, indépendant du réseau.

\section{Bracelet}

Le bracelet est un firmware PlatformIO Arduino pour ESP32-C3. Il lit le BMI270, calcule un score d'activité et envoie des paquets ESP-NOW à la station.

\begin{center}
  \centering
  
  \textbf{Diagramme: flux firmware du bracelet}
\end{center}

\subsection{Activité}

Le firmware lit l'accéléromètre et le gyroscope à 50 Hz et accumule une énergie sur des fenêtres de 200 ms. Une fenêtre comportant au moins 80 ms valides et atteignant le seuil 1,333,333 devient un événement identifié. Le bracelet conserve le plus récent pendant dix secondes et le retransmet jusqu'à confirmation de la station.

La station revalide l'énergie et calcule l'âge de l'événement à partir de l'uptime bracelet. Un événement reçu avec quatre secondes de retard ne donne donc que les six secondes restantes. Les mesures prises pendant la vibration du moteur et ses 450 ms de stabilisation sont ignorées.

\subsection{Flux ESP-NOW}

\begin{center}
  \centering
  
  \textbf{Diagramme: flux des paquets ESP-NOW}
\end{center}

Les paquets du protocole ESP-NOW version 2 commencent par un type de message, un rôle émetteur, un identifiant de périphérique, une séquence et un uptime. Le bracelet diffuse \texttt{bracelet\_status} avec sa session de démarrage, son dernier événement de mouvement non confirmé et l'identifiant de vibration réellement exécuté. La station diffuse \texttt{station\_control} avec les confirmations correspondantes; le bracelet peut alors se verrouiller temporairement sur le canal reçu. Les deux cartes doivent être mises à jour ensemble car les paquets version 1 sont rejetés.

Le bracelet ne contacte pas Supabase. Il ne décide pas de l'état final de l'alarme.

\section{Contrats inter-systèmes}

\subsection{États}

Les états station et bracelet sont partagés entre firmware, Supabase et PWA. Ils doivent rester synchronisés avec \texttt{ARCHITECTURE.md}, le SQL Supabase et les types TypeScript.

\begin{itemize}
  \item Station: \texttt{idle}, \texttt{armed}, \texttt{ringing}, \texttt{validating\_activity}, \texttt{stopped}, \texttt{fault}.
  \item Bracelet: \texttt{unknown}, \texttt{ready}, \texttt{low\_battery}, \texttt{fault}.
\end{itemize}

\subsection{Codes de problème}

Les principaux codes v1 sont:

\begin{itemize}
  \item \texttt{none}, \texttt{wifi\_unavailable}, \texttt{supabase\_unavailable}, \texttt{time\_unknown};
  \item \texttt{no\_valid\_alarm\_config}, \texttt{music\_stream\_failed}, \texttt{fallback\_audio\_failed};
  \item \texttt{bracelet\_missing}, \texttt{bracelet\_low\_battery}, \texttt{bracelet\_fault};
  \item \texttt{sensor\_fault}, \texttt{audio\_fault}, \texttt{unknown\_fault}.
\end{itemize}

\subsection{Batterie}

La station et le bracelet publient des tensions batterie brutes. L'affichage en pourcentage est dérivé côté PWA. Pour v1, le bracelet est considéré faible sous 30\% et bloquant avant alarme sous 20\%. Si la tension ne peut pas être mesurée, le système doit publier une valeur inconnue plutôt que simuler une précision.

\section{Matériel}

Les composants listés dans \texttt{composants.txt} sont considérés comme fixes sauf validation explicite. Les éléments principaux sont:

\begin{itemize}
  \item ESP32 pour la station;
  \item ESP32-C3 pour le bracelet;
  \item BMI270 pour le mouvement;
  \item PCM5102A comme DAC I2S;
  \item PAM8403 comme amplificateur;
  \item batteries LiPo 1S;
  \item modules de charge IP2312;
  \item pogo pins, PTC réarmables et LDO 3.3 V.
\end{itemize}

Les changements de batterie, charge, connecteur, PCB, boîtier ou chaîne audio doivent être traités comme des décisions matérielles importantes.

\section{Structure du dépôt}

\begin{longtable}{>{\ttfamily}p{0.34\linewidth}p{0.58\linewidth}}
\toprule
\normalfont Chemin & Rôle \\
\midrule
\endhead
ARCHITECTURE.md & Contrats canoniques entre PWA, station, bracelet et Supabase. \\
database/supabase & SQL concret pour le backend v1. \\
code/app mobile & PWA Vue/Vite. \\
code/app mobile/UML & Diagrammes de cas d'utilisation et flux utilisateur. \\
code/boite hp & Firmware PlatformIO de la station. \\
code/boite hp/UML & Diagrammes d'architecture et d'état station. \\
code/bracelet & Firmware PlatformIO du bracelet. \\
code/bracelet/UML & Diagrammes firmware et ESP-NOW du bracelet. \\
schema/bracelet & Sources KiCad du bracelet. \\
doc & Rapport LaTeX et PDF généré manuellement. \\
\bottomrule
\end{longtable}

\section{Limites connues}

\begin{itemize}
  \item Le modèle Supabase sans authentification est uniquement un raccourci prototype personnel.
  \item La portée ESP-NOW doit être validée en conditions réelles.
  \item Les seuils d'activité et de batterie doivent être calibrés avec le matériel final.
  \item Le fallback local protège contre l'échec du streaming, mais ne remplace pas la configuration Supabase normale.
  \item Le rapport est un artefact manuel: il doit être mis à jour quand l'architecture, les contrats ou les comportements significatifs changent.
\end{itemize}

\section{Conclusion}

Le système Starter est organisé autour d'une séparation stricte des responsabilités. La PWA configure, Supabase stocke et expose, le bracelet mesure, et la station décide. Cette séparation permet de développer chaque partie indépendamment tant que les contrats de \texttt{ARCHITECTURE.md} restent respectés.

\end{document}

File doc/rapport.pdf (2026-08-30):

## Starter Rapport d’architecture et de compréhension du code

Projet personnel de réveil actif

30 août 2026

## Table des matières

1 Objectif du projet | 2
2 Vue d’ensemble de l’architecture | 2
3 PWA mobile | 2
4 Backend Supabase | 4
5 Station de chevet | 4
6 Bracelet | 6
7 Contrats inter-systèmes | 9
8 Matériel | 9
9 Structure du dépôt | 9
10 Limites connues | 10
11 Conclusion | 10

## 1 Objectif du projet

Starter est un système de réveil personnel conçu pour rendre le retour au sommeil difficile. Le principe produit est volontairement simple : l’utilisateur prépare le réveil le soir, puis le système impose une activité physique minimale pendant les quinze premières minutes après l’heure configurée.
Le projet v1 est composé de trois parties actives :

— une station de chevet, située dans code/boite hp, qui joue le rôle d’autorité centrale de l’alarme ;
— un bracelet dédié, situé dans code/bracelet, qui mesure l’activité et la transmet à la station ; — une PWA mobile Vue/Vite, située dans code/app mobile, qui configure l’alarme et la musique via Supabase.

La règle centrale est que la station décide quand l’alarme démarre, quand le son est audible, et quand le cycle est terminé. La PWA ne déclenche pas l’alarme directement. Le bracelet ne stoppe pas l’alarme : il fournit uniquement une mesure d’activité que la station interprète.

## 2 Vue d’ensemble de l’architecture

Le flux de configuration v1 est :

PWA -> Supabase -> station

Le flux d’activité est :

bracelet -> ESP-NOW -> station

Supabase est utilisé pour stocker la musique, la sélection audio, la prochaine alarme et les états visibles par l’application. ESP-NOW est utilisé entre le bracelet et la station afin d’éviter un comportement WiFi lourd côté bracelet. Le transport ESP-NOW reste une hypothèse à valider physiquement sur la distance réelle d’utilisation.

### 2.1 Règles produit non négociables

— La station reste l’autorité centrale.
— Supabase est utilisé pour la configuration et les musiques en v1.
— Le bracelet communique avec la station par ESP-NOW en v1.
— Il n’existe pas de bouton normal stop ou snooze.
— Le son est contrôlé par l’activité du bracelet pendant une fenêtre fixe de dix minutes.
— Une panne technique bloquante doit placer le système dans un état de défaut visible.
— Un échec de streaming Supabase ne doit pas annuler le réveil : la station utilise un son local de secours.

## 3 PWA mobile

La PWA est l’interface utilisateur. Elle permet d’ajouter de la musique, de sélectionner une piste ou le fallback local, de configurer une alarme et de consulter l’état de la station et du bracelet.

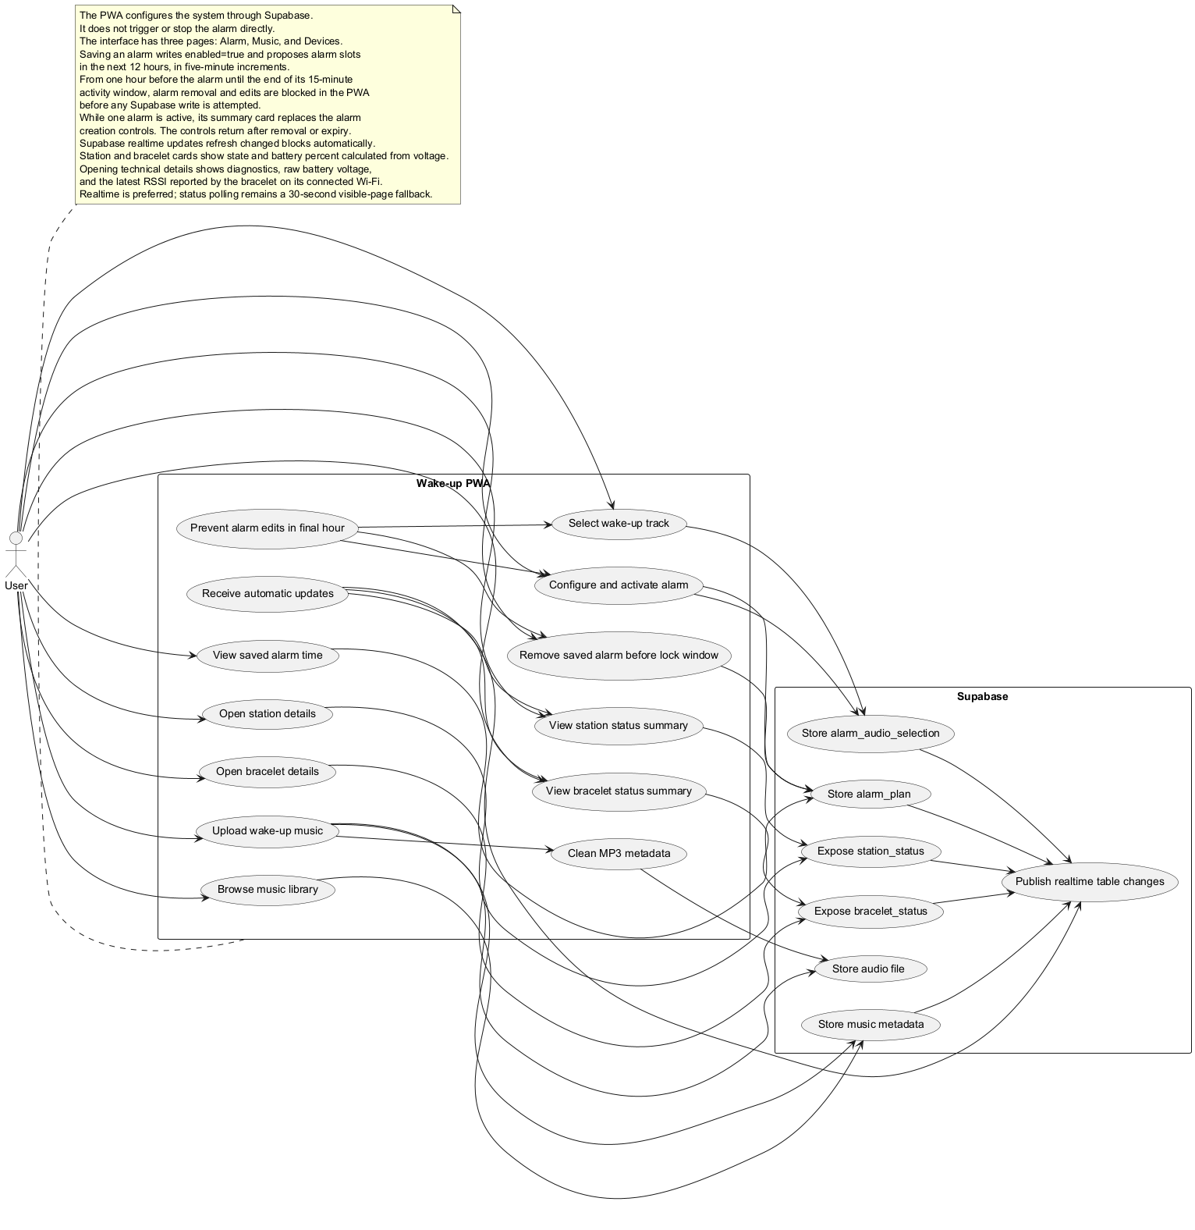
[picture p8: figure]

Diagramme : cas d’utilisation de la PWA

### 3.1 Responsabilités

— Uploader des fichiers audio vers le bucket Supabase wake-up-music. — Créer les métadonnées dans music_tracks.
— Écrire la configuration dans alarm_plan.
— Écrire la sélection audio dans alarm_audio_selection.
— Lire station_status et bracelet_status.
— Afficher les défauts sans devenir l’autorité d’alarme.

Le code actuel utilise Vue 3, Vite, TypeScript, @supabase/supabase-js et lucide-vue-next. La configuration Supabase côté PWA passe par VITE_SUPABASE_URL et VITE_SUPABASE_ANON_KEY. Cette clé anon est acceptable pour le prototype personnel, mais ce n’est pas un modèle de sécurité production.

### 3.2 Fenêtre de sélection d’alarme

La PWA propose des créneaux dans les douze prochaines heures, par pas de cinq minutes. Lorsqu’une alarme est sauvegardée, l’application incrémente la révision afin que la station puisse détecter une nouvelle configuration.

## 4 Backend Supabase

Supabase est le backend v1 pour les fichiers audio, la configuration de l’alarme et la publication des états. Le schéma SQL concret se trouve dans database/supabase/v1_schema.sql.

Table | Rôle
music_tracks | Bibliothèque des fichiers audio uploadés, avec titre, chemin de
| stockage, URL publique et disponibilité.
alarm_plan | Ligne unique main contenant activation, date, heure locale, ti-
| mezone et révision.
alarm_audio_selection | Ligne unique main contenant la source audio, la piste sélection-
| née et le volume.
station_status | État publié par la station : état courant, défaut, message, ré-
| vision active, tension batterie.
bracelet_status | État du bracelet vu par la station : état, défaut, message, ten-
| sion batterie, dernière réception.

Le bucket Supabase wake-up-music accepte les fichiers audio MPEG, WAV, OGG et MP4 audio jusqu’à 50 MiB. Les politiques RLS actuelles autorisent le client anon à lire et écrire les tables v1 et le bucket. Cette décision est explicitement limitée au prototype personnel.

## 5 Station de chevet

La station est un firmware PlatformIO Arduino pour ESP32. Elle synchronise l’heure, charge la configuration depuis Supabase, reçoit la télémétrie du bracelet, joue la musique sélectionnée et applique la logique d’alarme.

Diagramme : flux de

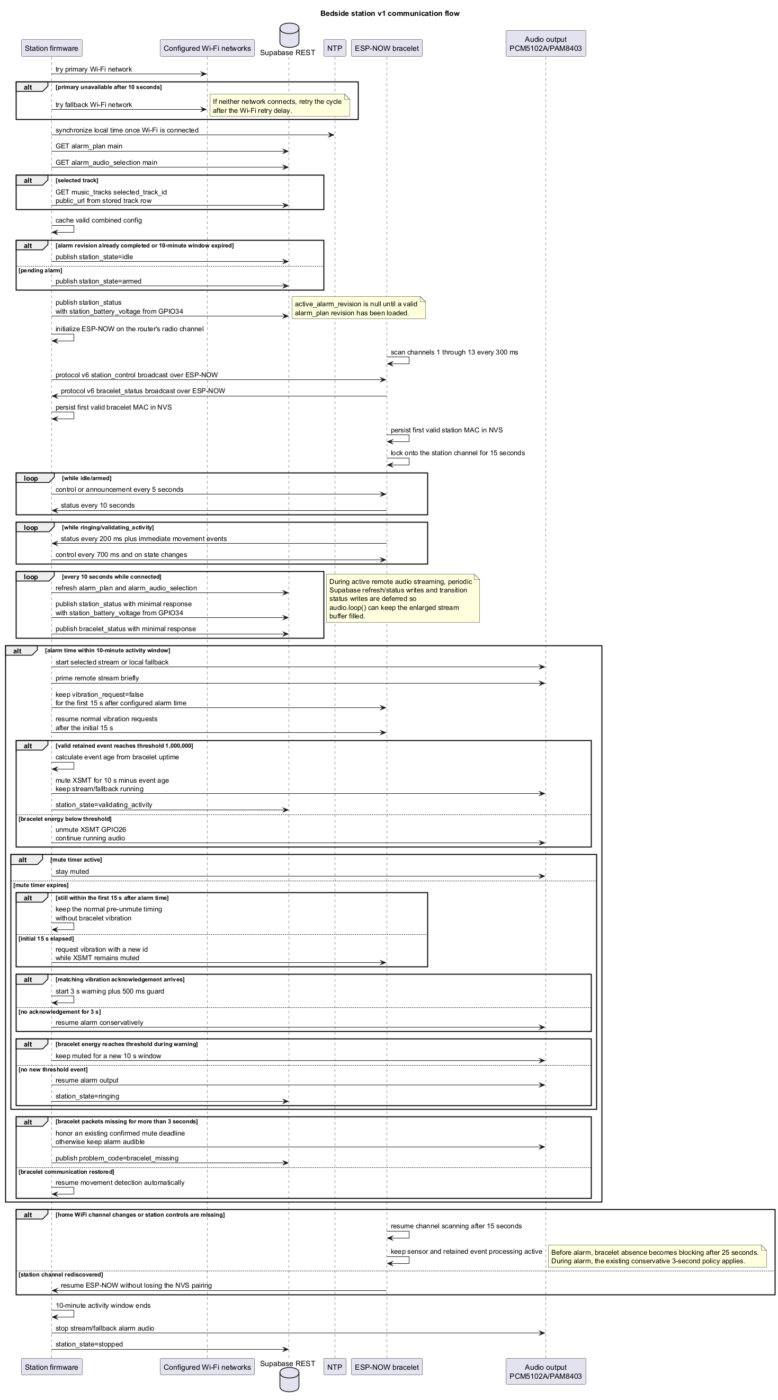
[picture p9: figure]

communication de la station

### 5.1 Responsabilités

— Connexion WiFi et synchronisation NTP.
— Lecture de alarm_plan, alarm_audio_selection et music_tracks.
— Cache local de la dernière configuration valide.
— Streaming de l’URL publique Supabase via la chaîne audio PCM5102A/PAM8403. — Fallback local généré si la musique Supabase échoue.
— Réception des paquets bracelet_status ESP-NOW.
— Envoi optionnel de station_control au bracelet.
— Publication de station_status et bracelet_status.

### 5.2 Machine d’état

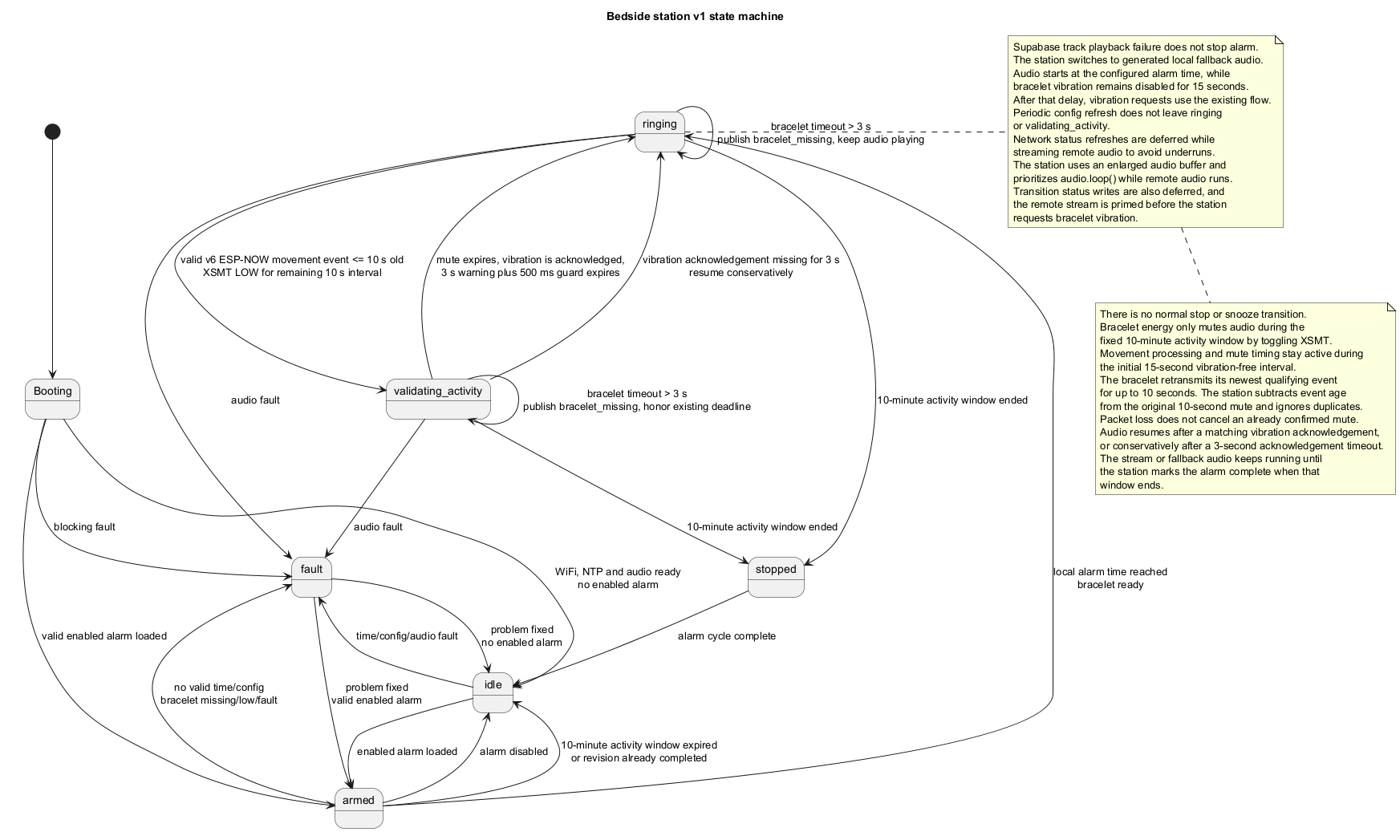
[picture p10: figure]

Diagramme : machine d’état v1 de la station

Les états exposés par la station sont idle, armed, ringing, validating_activity, stopped et fault. Le passage en ringing se produit lorsque l’heure locale configurée est atteinte et que les prérequis sont valides. Le passage en validating_activity signifie que la station a confirmé un événement de mouvement encore valable ; elle coupe alors la sortie audio via XSMT pour la partie restante de l’intervalle de dix secondes, mais le cycle d’alarme continue.
Une perte ESP-NOW supérieure à trois secondes publie bracelet_missing. Elle n’annule plus une sourdine déjà accordée. À son expiration, la station demande une vibration identifiée et attend que le bracelet confirme le démarrage réel du moteur avant de laisser trois secondes à l’utilisateur. Sans confirmation après trois secondes, la musique reprend afin qu’une déconnexion ne puisse pas neutraliser le réveil.
La fenêtre d’activité dure dix minutes à partir de l’heure configurée. À la fin de cette fenêtre, la station arrête le son et marque la révision comme terminée. Il n’y a pas de transition stop ou snooze normale depuis ringing ou validating_activity.

### 5.3 Défauts et fallback

Avant l’alarme, les défauts bloquants incluent l’absence d’heure valide, l’absence de configuration valide, un bracelet manquant ou en défaut, une batterie bracelet trop basse et un problème audio. Dans ces cas, la station doit publier un défaut visible.
L’échec du streaming musical au moment du réveil n’est pas bloquant pour le réveil lui-même. La station bascule sur un son local généré, indépendant du réseau.

## 6 Bracelet

Le bracelet est un firmware PlatformIO Arduino pour ESP32-C3. Il lit le BMI270, calcule un score d’activité et envoie des paquets ESP-NOW à la station.

Diagramme : flux firmware du

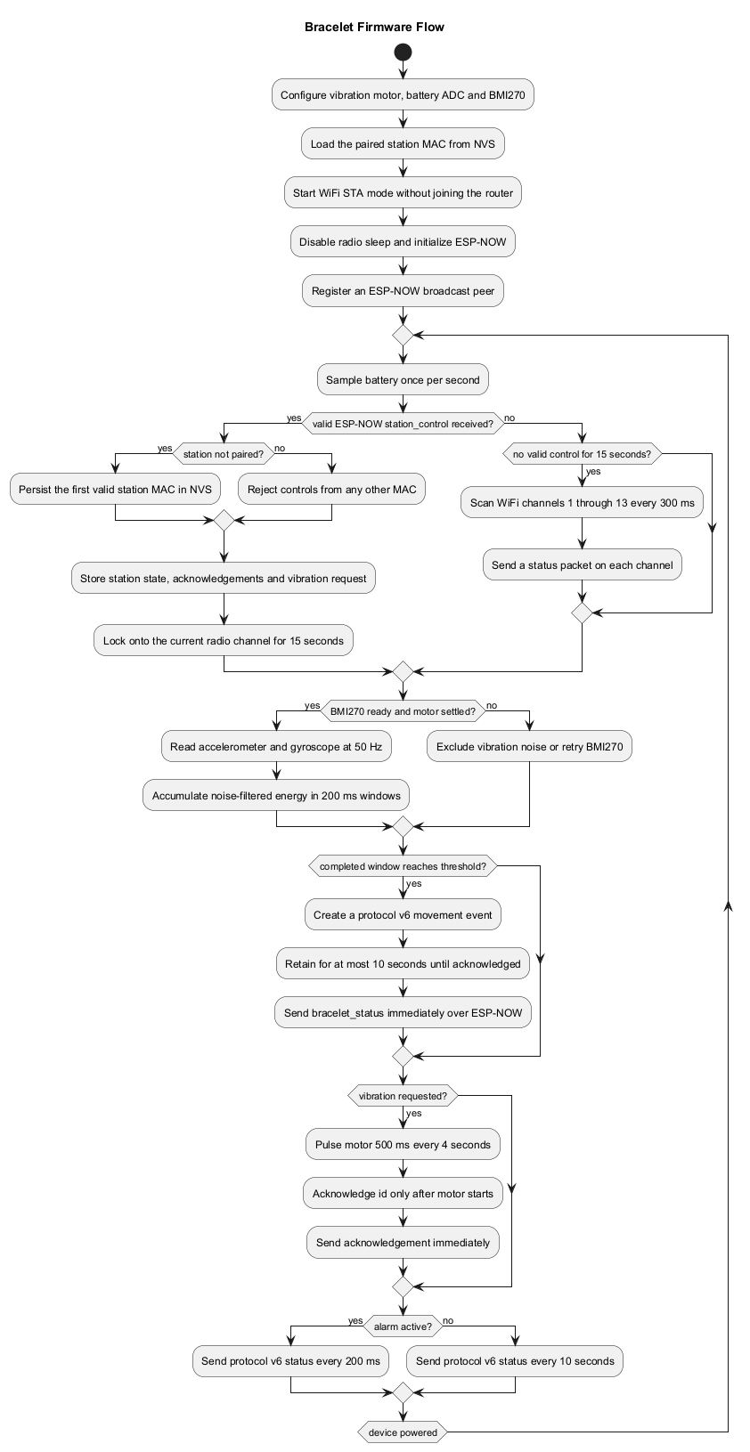
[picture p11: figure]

bracelet

### 6.1 Activité

Le firmware lit l’accéléromètre et le gyroscope à 50 Hz et accumule une énergie sur des fenêtres de 200 ms. Une fenêtre comportant au moins 80 ms valides et atteignant le seuil 1,333,333 devient un événement identifié. Le bracelet conserve le plus récent pendant dix secondes et le retransmet jusqu’à confirmation de la station.
La station revalide l’énergie et calcule l’âge de l’événement à partir de l’uptime bracelet. Un événement reçu avec quatre secondes de retard ne donne donc que les six secondes restantes. Les mesures prises pendant la vibration du moteur et ses 450 ms de stabilisation sont ignorées.

### 6.2 Flux ESP-NOW

Diagramme : flux des

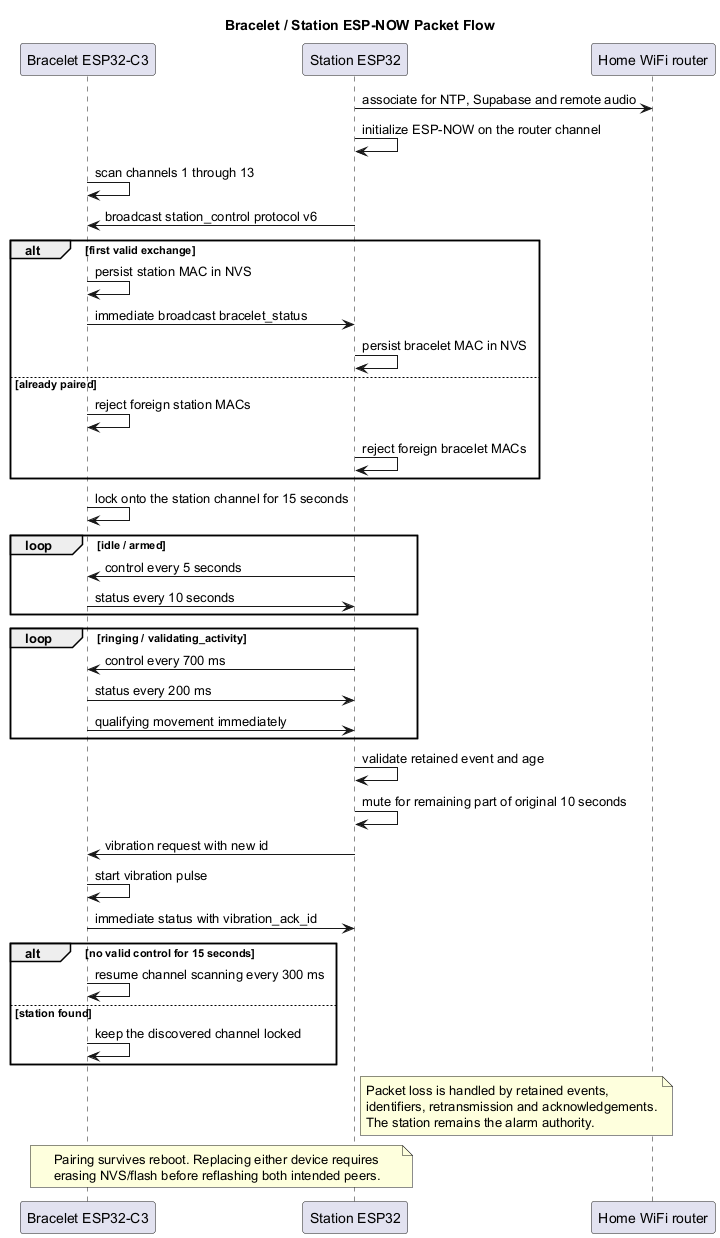
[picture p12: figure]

paquets ESP-NOW

Les paquets du protocole ESP-NOW version 2 commencent par un type de message, un rôle émetteur, un identifiant de périphérique, une séquence et un uptime. Le bracelet diffuse bracelet_status avec sa session de démarrage, son dernier événement de mouvement non confirmé et l’identifiant de vibration réellement exécuté. La station diffuse station_control avec les confirmations correspondantes ; le bracelet peut alors se verrouiller temporairement sur le canal reçu. Les deux cartes doivent être mises à jour ensemble car les paquets version 1 sont rejetés.
Le bracelet ne contacte pas Supabase. Il ne décide pas de l’état final de l’alarme.

## 7 Contrats inter-systèmes

### 7.1 États

Les états station et bracelet sont partagés entre firmware, Supabase et PWA. Ils doivent rester synchronisés avec ARCHITECTURE.md, le SQL Supabase et les types TypeScript.

— Station : idle, armed, ringing, validating_activity, stopped, fault.
— Bracelet : unknown, ready, low_battery, fault.

### 7.2 Codes de problème

Les principaux codes v1 sont :

— none, wifi_unavailable, supabase_unavailable, time_unknown ;
— no_valid_alarm_config, music_stream_failed, fallback_audio_failed ; — bracelet_missing, bracelet_low_battery, bracelet_fault ;
— sensor_fault, audio_fault, unknown_fault.

### 7.3 Batterie

La station et le bracelet publient des tensions batterie brutes. L’affichage en pourcentage est dérivé côté PWA. Pour v1, le bracelet est considéré faible sous 30% et bloquant avant alarme sous 20%. Si la tension ne peut pas être mesurée, le système doit publier une valeur inconnue plutôt que simuler une précision.

## 8 Matériel

Les composants listés dans composants.txt sont considérés comme fixes sauf validation explicite. Les éléments principaux sont :

— ESP32 pour la station ;
— ESP32-C3 pour le bracelet ;
— BMI270 pour le mouvement ; — PCM5102A comme DAC I2S ; — PAM8403 comme amplificateur ;
— batteries LiPo 1S ;
— modules de charge IP2312 ;
— pogo pins, PTC réarmables et LDO 3.3 V.

Les changements de batterie, charge, connecteur, PCB, boîtier ou chaîne audio doivent être traités comme des décisions matérielles importantes.

## 9 Structure du dépôt

Chemin | Rôle
ARCHITECTURE.md | Contrats canoniques entre PWA, station, bracelet et Su-
| pabase.
database/supabase | SQL concret pour le backend v1.
code/app mobile | PWA Vue/Vite.
code/app mobile/UML | Diagrammes de cas d’utilisation et flux utilisateur.
code/boite hp | Firmware PlatformIO de la station.
code/boite hp/UML | Diagrammes d’architecture et d’état station.
code/bracelet | Firmware PlatformIO du bracelet.

Chemin | Rôle
code/bracelet/UML | Diagrammes firmware et ESP-NOW du bracelet.
schema/bracelet | Sources KiCad du bracelet.
doc | Rapport LaTeX et PDF généré manuellement.

## 10 Limites connues

— Le modèle Supabase sans authentification est uniquement un raccourci prototype personnel. — La portée ESP-NOW doit être validée en conditions réelles.
— Les seuils d’activité et de batterie doivent être calibrés avec le matériel final.
— Le fallback local protège contre l’échec du streaming, mais ne remplace pas la configuration Supabase normale.
— Le rapport est un artefact manuel : il doit être mis à jour quand l’architecture, les contrats ou les comportements significatifs changent.

## 11 Conclusion

Le système Starter est organisé autour d’une séparation stricte des responsabilités. La PWA configure, Supabase stocke et expose, le bracelet mesure, et la station décide. Cette séparation permet de développer chaque partie indépendamment tant que les contrats de ARCHITECTURE.md restent respectés.

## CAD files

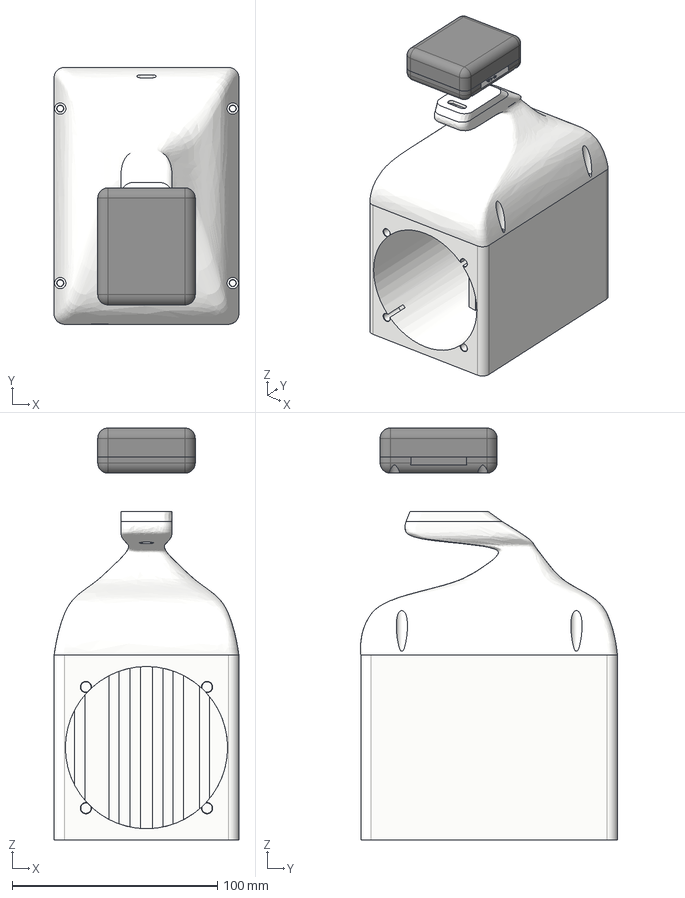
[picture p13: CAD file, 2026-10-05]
CAO/Starter assembly.step
90.0 x 125.1 x 200.6 mm
Box bracelet
base bracelet
Boite resonance
Cache station
cache cache station

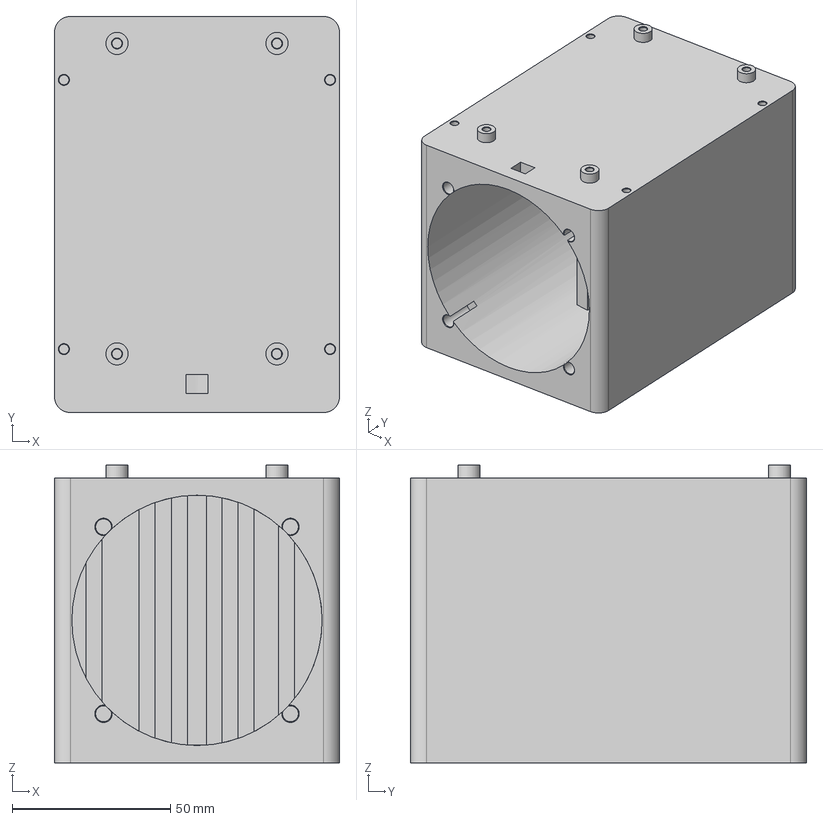
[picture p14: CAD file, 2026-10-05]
CAO/Boite resonance.step
90.0 x 125.0 x 94.0 mm

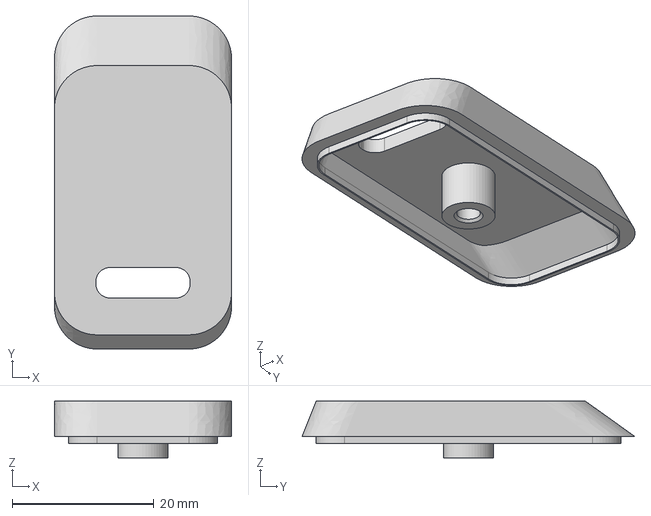
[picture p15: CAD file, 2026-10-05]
CAO/cache cache station.step
25.0 x 47.0 x 8.00 mm

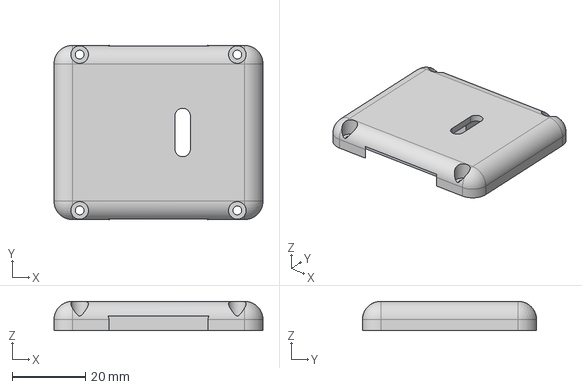
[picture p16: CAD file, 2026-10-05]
CAO/base bracelet.step
57.0 x 47.5 x 8.00 mm

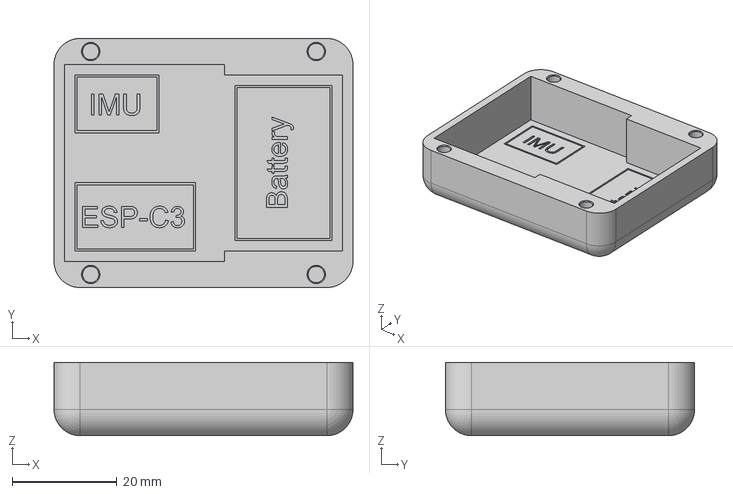
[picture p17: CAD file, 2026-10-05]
CAO/Box bracelet.step
57.0 x 47.5 x 14.0 mm

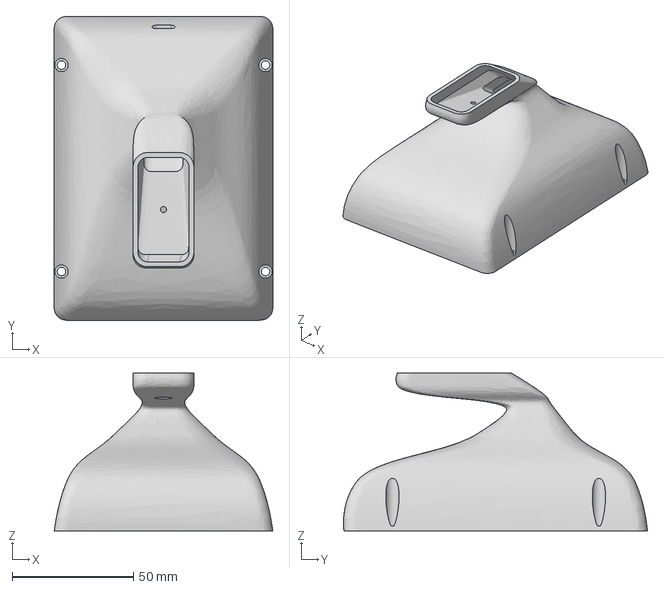
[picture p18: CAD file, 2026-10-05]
CAO/Cache station.step
90.0 x 125.1 x 65.0 mm

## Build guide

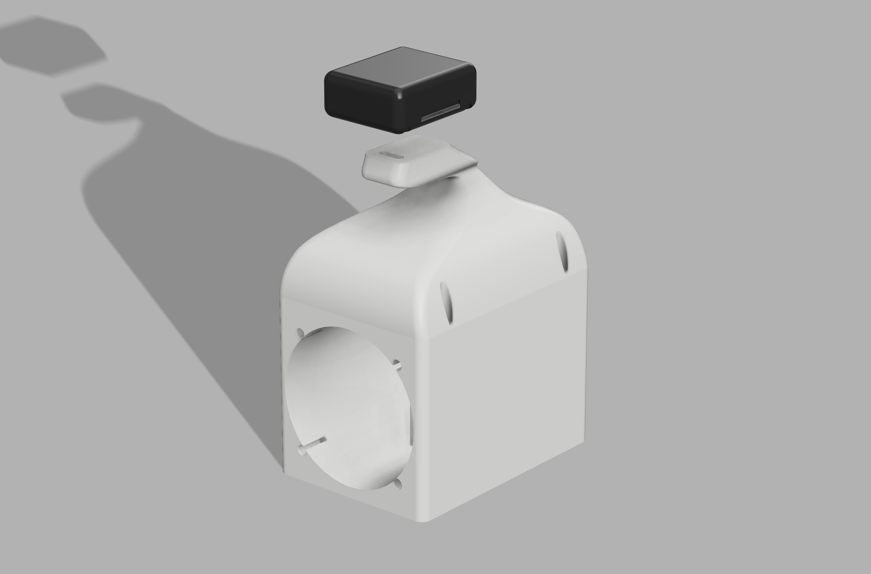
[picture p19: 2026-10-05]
images/renduassemblage.png

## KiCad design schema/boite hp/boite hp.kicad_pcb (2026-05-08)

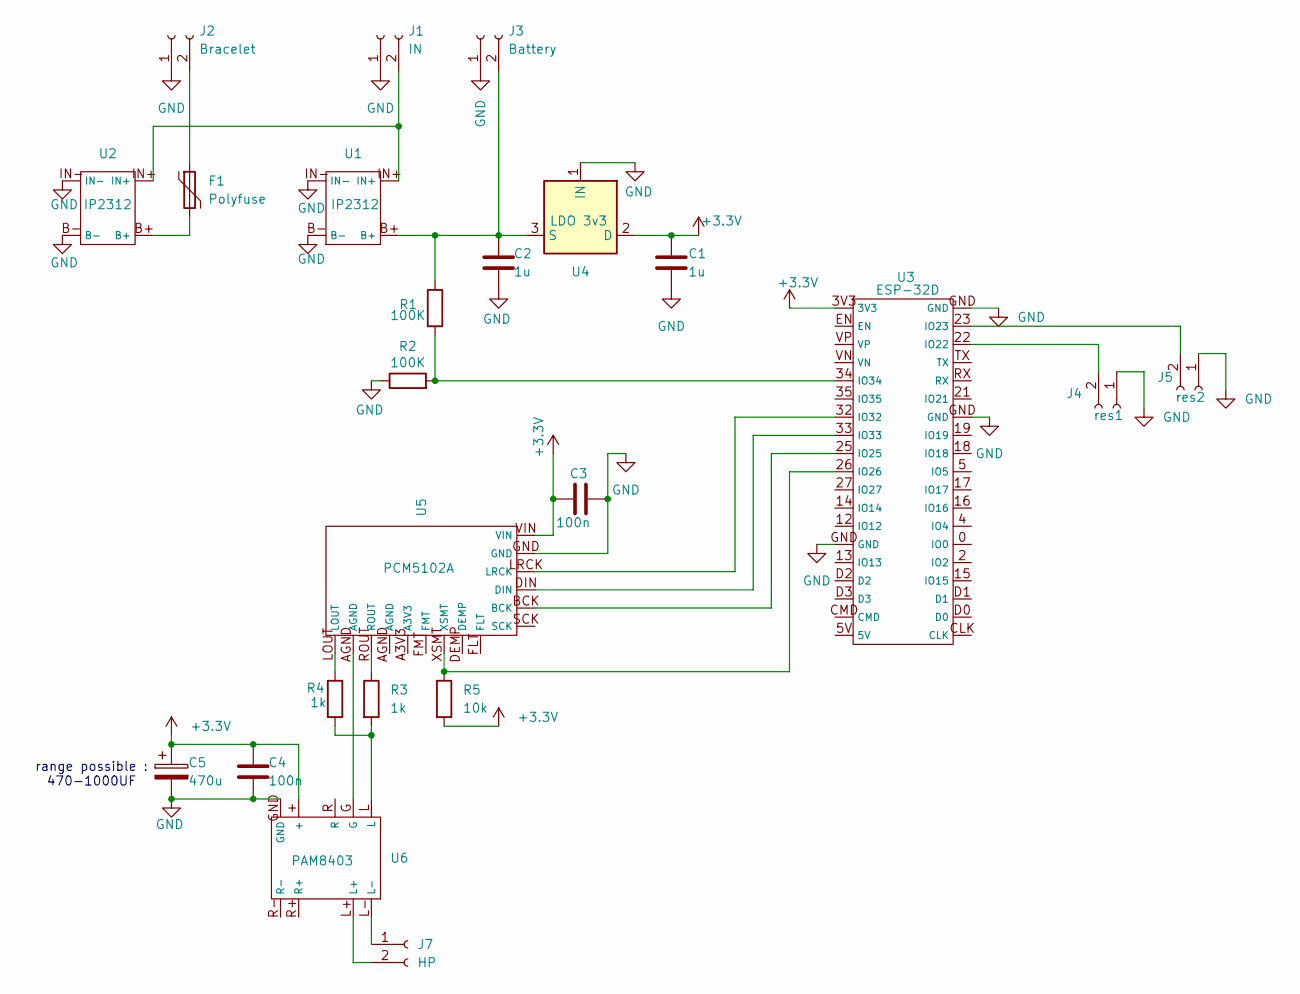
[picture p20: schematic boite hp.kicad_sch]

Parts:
C1, C2: 1u; C_0805_2012Metric
C3, C4: 100n; C_0805_2012Metric
C5: 470u; CP_Radial_D8.0mm_P3.50mm
F1: Polyfuse; C_Disc_D5.0mm_W2.5mm_P5.00mm
J1: IN; JST_PH_B2B-PH-K_1x02_P2.00mm_Vertical
J2: Bracelet; JST_PH_B2B-PH-K_1x02_P2.00mm_Vertical
J3: Battery; JST_PH_B2B-PH-K_1x02_P2.00mm_Vertical
J4: res1; JST_PH_B2B-PH-K_1x02_P2.00mm_Vertical
J5: res2; JST_PH_B2B-PH-K_1x02_P2.00mm_Vertical
J7: HP; JST_PH_B2B-PH-K_1x02_P2.00mm_Vertical
R1, R2: 100K; R_1206_3216Metric
R3, R4: 1k; R_1206_3216Metric
R5: 10k; R_1206_3216Metric
U1, U2: IP2312
U3: ESP-32D; ESP-32D devkit
U4: LDO 3v3; SOT-223-3_TabPin2
U5: PCM5102A; PCM5102A Module
U6: PAM8403; PAM8403 Module

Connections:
+3.3V: C1.1, C3.1, C4.1, C5.1, R5.2, U3.3V3, U4.2 (D), U5.VIN, U6.+
GND: C1.2, C2.2, C3.2, C4.2, C5.2, J1.1, J2.1, J3.1, J4.1, J5.1, R2.1, U1.B-, U1.IN-, U2.B-, U2.IN-, U3.GND, U4.1 (IN), U5.GND, U6.GND
unnamed: F1.2, U2.B+
unnamed: J1.2, U1.IN+, U2.IN+
unnamed: F1.1, J2.2
unnamed: C2.1, J3.2, R1.1, U1.B+, U4.3 (S)
unnamed: J4.2, U3.22 (IO22)
unnamed: J5.2, U3.23 (IO23)
unnamed: J7.1, U6.L-
unnamed: J7.2, U6.L+
unnamed: R3.1, U5.ROUT
unnamed: R3.2, R4.2, U6.L
unnamed: R4.1, U5.LOUT
unnamed: U3.25 (IO25), U5.BCK
unnamed: R5.1, U3.26 (IO26), U5.XSMT
unnamed: U3.32 (IO32), U5.LRCK
unnamed: U3.33 (IO33), U5.DIN
unnamed: R1.2, R2.2, U3.34 (IO34)
unnamed: U5.AGND, U6.G

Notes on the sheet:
range possible : 470-1000UF

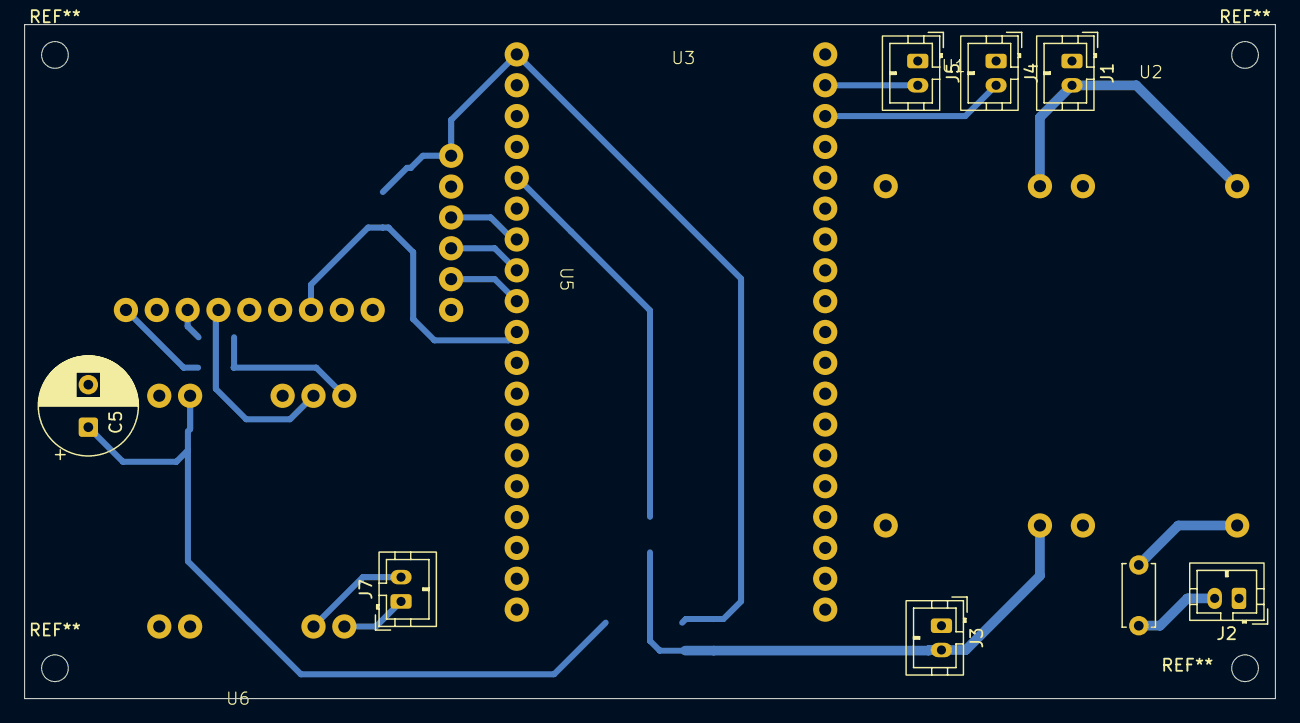
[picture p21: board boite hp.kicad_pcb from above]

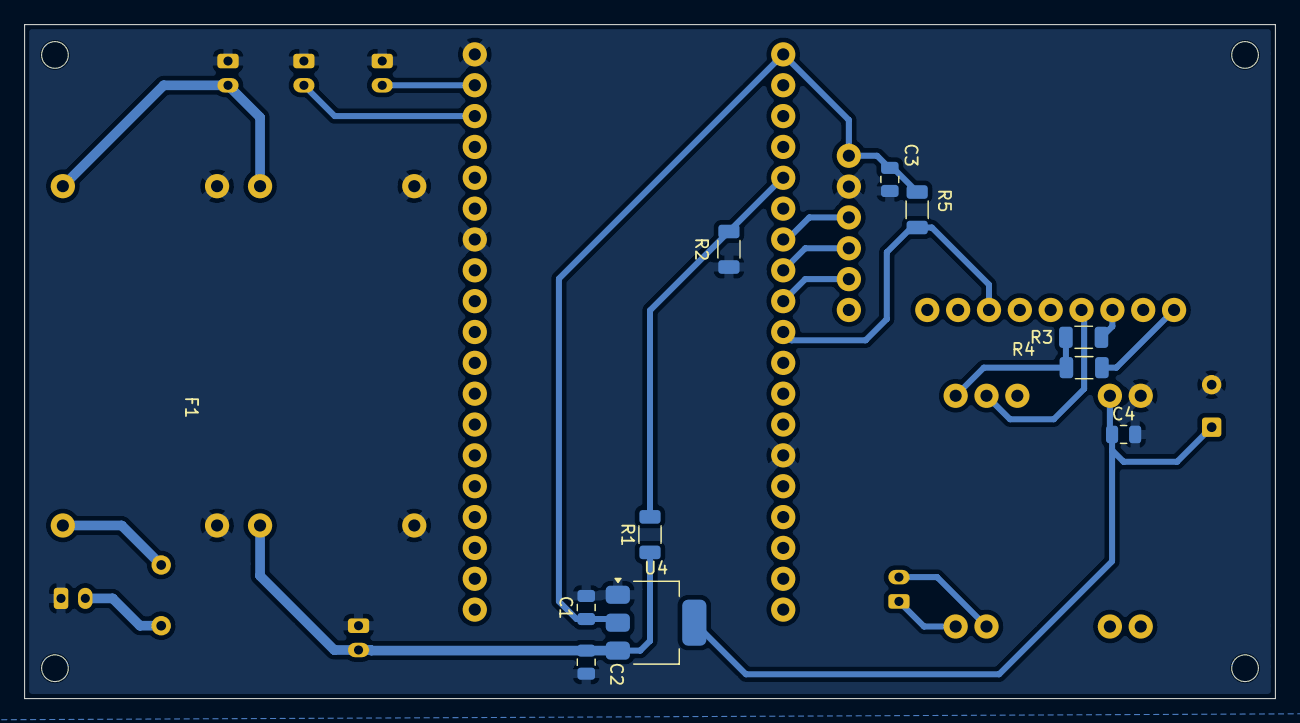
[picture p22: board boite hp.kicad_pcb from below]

Board: 2 copper layers, 103.0 x 55.5 mm, 23 parts (10 on the bottom side), 19 nets.

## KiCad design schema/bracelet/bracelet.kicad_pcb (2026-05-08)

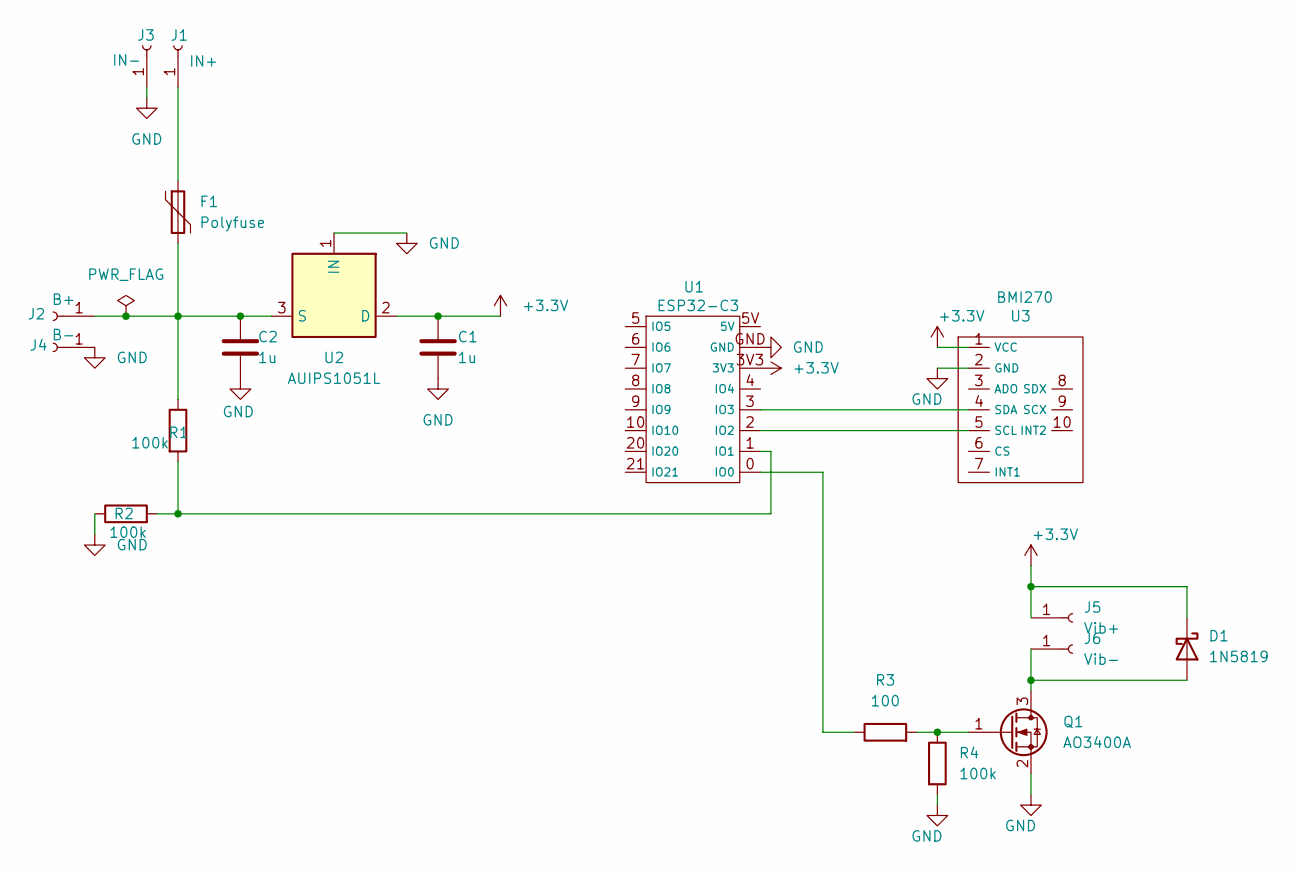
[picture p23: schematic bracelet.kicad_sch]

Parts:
C1, C2: 1u; C_0805_2012Metric
D1: 1N5819; D_SMA
F1: Polyfuse; C_Disc_D5.0mm_W2.5mm_P5.00mm
J1: IN+; SolderWirePad_1x01_SMD_2x4mm
J2: B+; SolderWirePad_1x01_SMD_2x4mm
J3: IN-; SolderWirePad_1x01_SMD_2x4mm
J4: B-; SolderWirePad_1x01_SMD_2x4mm
J5: Vib+; SolderWirePad_1x01_SMD_2x4mm
J6: Vib-; SolderWirePad_1x01_SMD_2x4mm
Q1: AO3400A; SOT-23
R1, R2, R4: 100k; R_1206_3216Metric
R3: 100; R_1206_3216Metric
U1: ESP32-C3; ESP32-C3 HW-466B
U2: AUIPS1051L; SOT-223-3_TabPin2
U3: BMI270; BMI270 module

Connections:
+3.3V: C1.1, D1.1 (K), J5.1 (Pin_1_1), U1.3V3, U2.2 (D), U3.1 (VCC)
GND: C1.2, C2.2, J3.1 (Pin_1_1), J4.1 (Pin_1_1), Q1.2 (S), R2.1, R4.2, U1.GND, U2.1 (IN), U3.2 (GND)
unnamed: D1.2 (A), J6.1 (Pin_1_1), Q1.3 (D)
unnamed: F1.1, J1.1 (Pin_1_1)
unnamed: C2.1, F1.2, J2.1 (Pin_1_1), R1.1, U2.3 (S)
unnamed: Q1.1 (G), R3.2, R4.1
unnamed: R3.1, U1.0 (IO0)
unnamed: R1.2, R2.2, U1.1 (IO1)
unnamed: U1.2 (IO2), U3.5 (SCL)
unnamed: U1.3 (IO3), U3.4 (SDA)

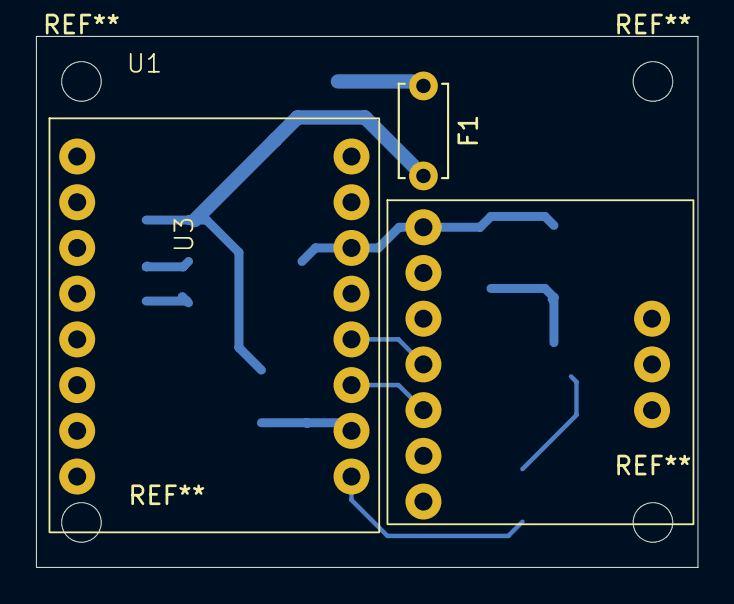
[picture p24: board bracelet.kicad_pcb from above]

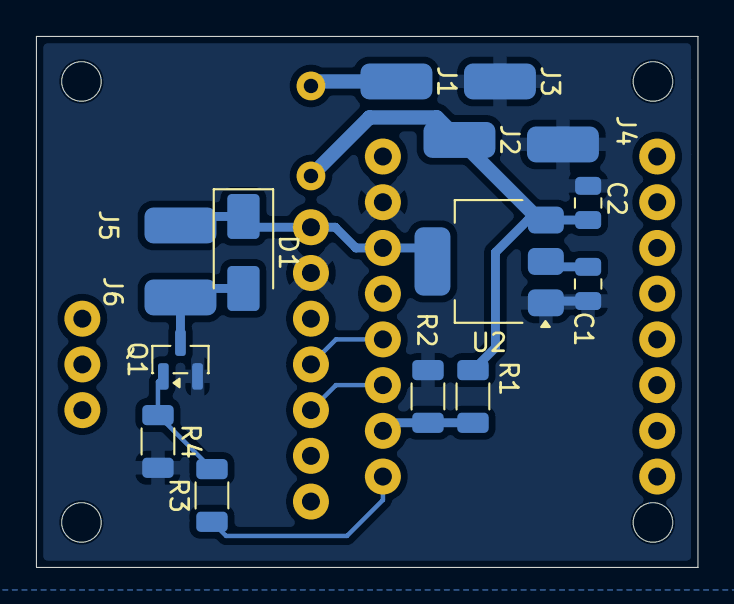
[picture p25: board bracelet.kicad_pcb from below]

Board: 2 copper layers, 36.8 x 29.5 mm, 18 parts (15 on the bottom side), 10 nets.

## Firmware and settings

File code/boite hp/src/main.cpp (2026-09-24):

#include <Arduino.h>
#include <ArduinoJson.h>
#include <Audio.h>
#include <HTTPClient.h>
#include <Preferences.h>
#include <WiFi.h>
#include <esp_now.h>
#include <esp_system.h>
#include <esp_wifi.h>
#include <time.h>

#include <driver/i2s.h>
#include "../../bracelet_station_protocol.h"

#if __has_include("secrets.h")
#include "secrets.h"
#else
#include "secrets.example.h"
#endif

static const int PIN_LRCK = 32;
static const int PIN_DIN = 33;
static const int PIN_BCK = 25;
static const int PIN_XSMT = 26;
static const int PIN_BATTERY_ADC = 34;

static const uint32_t CONFIG_REFRESH_MS = 10000;
static const uint32_t STATUS_PUBLISH_MS = 10000;
static const uint32_t ACTIVE_CONTROL_SEND_MS = 700;
static const uint32_t INACTIVE_CONTROL_SEND_MS = 5000;
static const uint32_t WIFI_RETRY_MS = 15000;
static const uint32_t WIFI_CONNECT_TIMEOUT_MS = 10000;
static const uint32_t SUPABASE_FAILURE_BACKOFF_MS = 30000;
// The ESP32 without PSRAM must keep enough contiguous internal heap for TLS.
// This remains comfortably above the audio library's MP3/AAC minimum buffer.
static const int AUDIO_BUFFER_RAM_BYTES = 24 * 1024;
static const int AUDIO_BUFFER_PSRAM_BYTES = 192 * 1024;
static const uint32_t ARMED_BRACELET_TIMEOUT_MS = 25000;
static const uint32_t RINGING_BRACELET_TIMEOUT_MS = 3000;
static const uint32_t VIBRATION_ACK_TIMEOUT_MS = 3000;
static const uint32_t PRE_UNMUTE_SECOND_VIBRATION_MS = 4000;
static const uint32_t PRE_UNMUTE_THIRD_VIBRATION_MS = 6000;
static const uint32_t PRE_UNMUTE_VIBRATION_ON_MS = 500;
static const uint32_t ENERGY_PRE_UNMUTE_WARNING_MS =
    PRE_UNMUTE_THIRD_VIBRATION_MS + PRE_UNMUTE_VIBRATION_ON_MS;
static const uint32_t ENERGY_UNMUTE_GRACE_MS = 500;
static const uint32_t REMOTE_AUDIO_PRIME_MS = 700;
static const uint32_t REMOTE_AUDIO_LOOP_BUDGET_MS = 20;
static const uint32_t REMOTE_AUDIO_AFTER_CONTROL_MS = 4;
static const time_t INITIAL_VIBRATION_DELAY_SECONDS = 15;
static const time_t ALARM_WINDOW_SECONDS = 10 * 60;
static const float BATTERY_DIVIDER_RATIO = 2.0F;
static const float BATTERY_EMPTY_V = 3.30F;
static const float BATTERY_FULL_V = 4.20F;
static const uint8_t BRACELET_BLOCKING_BATTERY_PERCENT = 20;
static const uint8_t BRACELET_LOW_BATTERY_PERCENT = 30;
static const i2s_port_t FALLBACK_I2S_PORT = I2S_NUM_0;
static const uint32_t FALLBACK_SAMPLE_RATE = 22050;
static const uint16_t FALLBACK_FRAMES = 256;

enum class StationState : uint8_t
{
  Idle = 0,
  Armed = 1,
  Ringing = 2,
  ValidatingActivity = 3,
  Stopped = 4,
  Fault = 5,
};

enum class ProblemCode : uint8_t
{
  None = 0,
  SupabaseUnavailable = 1,
  TimeUnknown = 2,
  NoValidAlarmConfig = 3,
  MusicStreamFailed = 4,
  FallbackAudioFailed = 5,
  BraceletMissing = 6,
  BraceletLowBattery = 7,
  SensorFault = 8,
};

enum class BraceletState : uint8_t
{
  Unknown = 0,
  Ready = 1,
  LowBattery = 2,
  Fault = 3,
};

struct AlarmConfig
{
  bool valid = false;
  bool enabled = false;
  bool useFallback = true;
  int revision = 0;
  int volumePercent = 80;
  time_t alarmAt = 0;
  String timezone = "Europe/Zurich";
  String selectedTrackUrl;
};

struct BraceletSnapshot
{
  BraceletState state = BraceletState::Unknown;
  ProblemCode problem = ProblemCode::None;
  bool vibrating = false;
  uint32_t energy = 0;
  uint16_t energyValidMs = 0;
  float batteryVoltage = -1.0F;
  int batteryPercent = -1;
  uint32_t lastSeenMs = 0;
  uint32_t sequence = 0;
  uint32_t bootSessionId = 0;
  uint32_t vibrationAckId = 0;
};

using BraceletStationProtocol::BraceletStatusPacket;
using BraceletStationProtocol::StationControlPacket;

static Audio audio;
static Preferences preferences;
static AlarmConfig alarmConfig;
static BraceletSnapshot bracelet;
static StationState stationState = StationState::Idle;
static ProblemCode problemCode = ProblemCode::None;
static String problemMessage = "";
static bool remoteAudioActive = false;
static bool fallbackAudioActive = false;
static bool alarmAudioMuted = false;
static bool espNowReady = false;
static bool braceletPaired = false;
static bool timeReady = false;
static float stationBatteryVoltage = -1.0F;
static uint32_t lastConfigRefreshMs = 0;
static uint32_t lastStatusPublishMs = 0;
static uint32_t lastControlSendMs = 0;
static uint32_t lastBraceletEspNowDebugMs = 0;
static uint32_t lastWifiCycleFailureMs = 0;
static uint32_t wifiConnectStartedMs = 0;
static uint8_t wifiNetworkIndex = 0;
static bool wifiConnectionInProgress = false;
static uint32_t lastSupabaseFailureMs = 0;
static uint32_t energyMuteUntilMs = 0;
static uint32_t unmuteWarningUntilMs = 0;
static uint32_t vibrationAckDeadlineMs = 0;
static uint32_t vibrationRequestId = 0;
static bool vibrationRequestActive = false;
static uint32_t acknowledgedBootSessionId = 0;
static uint32_t acknowledgedMovementEventId = 0;
static uint32_t processedMovementBootSessionId = 0;
static uint32_t processedMovementEventId = 0;
static uint32_t alarmAudioStartedMs = 0;
static bool stationControlDirty = false;
static uint32_t controlSequence = 0;
static uint8_t stationMac[6] = {0};
static uint8_t pairedBraceletId[6] = {0};
static BraceletStatusPacket pendingBraceletStatus = {};
static bool braceletStatusPending = false;
static portMUX_TYPE espNowMux = portMUX_INITIALIZER_UNLOCKED;
static int completedAlarmRevision = 0;
static bool pendingStationStatusPublish = false;
static bool pendingBraceletStatusPublish = false;

static const uint8_t BROADCAST_PEER[ESP_NOW_ETH_ALEN] = {0xff, 0xff, 0xff, 0xff, 0xff, 0xff};

static const char *stateName(StationState state)
{
  switch (state)
  {
  case StationState::Idle: return "idle";
  case StationState::Armed: return "armed";
  case StationState::Ringing: return "ringing";
  case StationState::ValidatingActivity: return "validating_activity";
  case StationState::Stopped: return "stopped";
  case StationState::Fault: return "fault";
  }
  return "fault";
}

static const char *braceletStateName(BraceletState state)
{
  switch (state)
  {
  case BraceletState::Unknown: return "unknown";
  case BraceletState::Ready: return "ready";
  case BraceletState::LowBattery: return "low_battery";
  case BraceletState::Fault: return "fault";
  }
  return "unknown";
}

static const char *problemName(ProblemCode code)
{
  switch (code)
  {
  case ProblemCode::None: return "none";
  case ProblemCode::SupabaseUnavailable: return "supabase_unavailable";
  case ProblemCode::TimeUnknown: return "time_unknown";
  case ProblemCode::NoValidAlarmConfig: return "no_valid_alarm_config";
  case ProblemCode::MusicStreamFailed: return "music_stream_failed";
  case ProblemCode::FallbackAudioFailed: return "fallback_audio_failed";
  case ProblemCode::BraceletMissing: return "bracelet_missing";
  case ProblemCode::BraceletLowBattery: return "bracelet_low_battery";
  case ProblemCode::SensorFault: return "sensor_fault";
  }
  return "sensor_fault";
}

static bool alarmIsActive()
{
  return stationState == StationState::Ringing || stationState == StationState::ValidatingActivity;
}

static bool alarmRevisionWasCompleted(const AlarmConfig &config)
{
  return config.revision >= 1 && config.revision == completedAlarmRevision;
}

static bool alarmIsStale(const AlarmConfig &config)
{
  if (!timeReady || !config.enabled || !config.alarmAt)
  {
    return false;
  }

  return time(nullptr) > config.alarmAt + ALARM_WINDOW_SECONDS;
}

static bool alarmShouldBeArmed(const AlarmConfig &config)
{
  return config.valid && config.enabled && !alarmRevisionWasCompleted(config) && !alarmIsStale(config);
}

static bool alarmCanStartNow(const AlarmConfig &config)
{
  if (!alarmShouldBeArmed(config) || !timeReady)
  {
    return false;
  }

  const time_t now = time(nullptr);
  return now >= config.alarmAt && now <= config.alarmAt + ALARM_WINDOW_SECONDS;
}

static bool alarmWindowIsOpen(const AlarmConfig &config)
{
  return alarmCanStartNow(config);
}

static bool alarmWindowHasEnded(const AlarmConfig &config)
{
  return config.valid && config.enabled && timeReady && time(nullptr) > config.alarmAt + ALARM_WINDOW_SECONDS;
}

static bool initialVibrationDelayIsActive()
{
  if (!timeReady || !alarmConfig.valid || !alarmConfig.enabled || !alarmConfig.alarmAt)
  {
    return false;
  }

  const time_t now = time(nullptr);
  return now >= alarmConfig.alarmAt &&
         now < alarmConfig.alarmAt + INITIAL_VIBRATION_DELAY_SECONDS;
}

static bool deadlineIsPending(uint32_t now, uint32_t deadline)
{
  return deadline != 0 && static_cast<int32_t>(deadline - now) > 0;
}

static bool eventIdIsNewer(uint32_t candidate, uint32_t previous)
{
  return candidate != 0 && (previous == 0 || static_cast<int32_t>(candidate - previous) > 0);
}

static void setVibrationRequest(bool active)
{
  if (active && initialVibrationDelayIsActive())
  {
    active = false;
  }

  if (active == vibrationRequestActive)
  {
    return;
  }

  vibrationRequestActive = active;
  if (active)
  {
    vibrationRequestId++;
    if (vibrationRequestId == 0)
    {
      vibrationRequestId = 1;
    }
  }
  stationControlDirty = true;
}

static bool energyKeepsAudioMuted()
{
  if (energyMuteUntilMs == 0)
  {
    return false;
  }

  const uint32_t now = millis();
  if (deadlineIsPending(now, energyMuteUntilMs))
  {
    unmuteWarningUntilMs = 0;
    vibrationAckDeadlineMs = 0;
    setVibrationRequest(false);
    return true;
  }

  if (vibrationAckDeadlineMs == 0 && unmuteWarningUntilMs == 0)
  {
    if (initialVibrationDelayIsActive())
    {
      setVibrationRequest(false);
      return true;
    }

    setVibrationRequest(true);
    vibrationAckDeadlineMs = now + VIBRATION_ACK_TIMEOUT_MS;
    Serial.printf("Waiting up to %lu ms for vibration acknowledgement %lu.\n",
                  static_cast<unsigned long>(VIBRATION_ACK_TIMEOUT_MS),
                  static_cast<unsigned long>(vibrationRequestId));
    return true;
  }

  if (vibrationAckDeadlineMs != 0)
  {
    if (bracelet.vibrationAckId == vibrationRequestId)
    {
      vibrationAckDeadlineMs = 0;
      unmuteWarningUntilMs = now + ENERGY_PRE_UNMUTE_WARNING_MS;
      Serial.printf("Vibration acknowledgement %lu received; starting 4s/2s three-vibration warning before unmute.\n",
                    static_cast<unsigned long>(vibrationRequestId));
      return true;
    }
    if (deadlineIsPending(now, vibrationAckDeadlineMs))
    {
      return true;
    }

    vibrationAckDeadlineMs = 0;
    energyMuteUntilMs = 0;
    Serial.println("Vibration acknowledgement timed out; resuming alarm audio.");
    return false;
  }

  if (deadlineIsPending(now, unmuteWarningUntilMs) ||
      now - unmuteWarningUntilMs < ENERGY_UNMUTE_GRACE_MS)
  {
    setVibrationRequest(true);
    return true;
  }

  energyMuteUntilMs = 0;
  unmuteWarningUntilMs = 0;
  return false;
}

static uint32_t energyMuteRemainingMs()
{
  const uint32_t now = millis();
  if (energyMuteUntilMs == 0)
  {
    return 0;
  }

  if (deadlineIsPending(now, energyMuteUntilMs))
  {
    return energyMuteUntilMs - now;
  }
  if (deadlineIsPending(now, vibrationAckDeadlineMs))
  {
    return vibrationAckDeadlineMs - now;
  }
  if (deadlineIsPending(now, unmuteWarningUntilMs))
  {
    return unmuteWarningUntilMs - now + ENERGY_UNMUTE_GRACE_MS;
  }
  return 0;
}

static void saveCompletedAlarmRevision(int revision)
{
  if (revision < 1 || completedAlarmRevision == revision)
  {
    return;
  }

  completedAlarmRevision = revision;
  preferences.begin("station", false);
  preferences.putInt("completedRev", completedAlarmRevision);
  preferences.end();
}

static void loadCompletedAlarmRevision()
{
  preferences.begin("station", true);
  completedAlarmRevision = preferences.getInt("completedRev", 0);
  preferences.end();
}

static StationState inactiveStateForAlarm(const AlarmConfig &config)
{
  return alarmShouldBeArmed(config) ? StationState::Armed : StationState::Idle;
}

static void setStationState(StationState state, ProblemCode code = ProblemCode::None, const String &message = "")
{
  const bool changed = stationState != state || problemCode != code || problemMessage != message;
  if (changed)
  {
    Serial.printf("Station state: %s, problem: %s, %s\n", stateName(state), problemName(code), message.c_str());
    stationControlDirty = true;
  }

  stationState = state;
  problemCode = code;
  problemMessage = message;
}

static void applyTimezone(const String &timezone)
{
  if (timezone != "Europe/Zurich")
  {
    Serial.printf("Unsupported timezone '%s'; using Europe/Zurich rules for v1.\n", timezone.c_str());
  }

  setenv("TZ", "CET-1CEST,M3.5.0/2,M10.5.0/3", 1);
  tzset();
}

static bool hasRealSupabaseConfig()
{
  return String(SUPABASE_URL).startsWith("https://") && String(SUPABASE_ANON_KEY).length() > 20;
}

static bool ensureWifi()
{
  if (WiFi.status() == WL_CONNECTED)
  {
    wifiConnectionInProgress = false;
    return true;
  }

  const uint32_t now = millis();
  const char *ssids[] = {WIFI_SSID, WIFI_FALLBACK_SSID};
  const char *passwords[] = {WIFI_PASSWORD, WIFI_FALLBACK_PASSWORD};
  const uint8_t networkCount = sizeof(ssids) / sizeof(ssids[0]);

  if (wifiConnectionInProgress && now - wifiConnectStartedMs < WIFI_CONNECT_TIMEOUT_MS)
  {
    return false;
  }

  const bool fallbackConfigured = strlen(WIFI_FALLBACK_SSID) > 0;
  if (wifiConnectionInProgress)
  {
    Serial.printf("WiFi connection to '%s' timed out\n", ssids[wifiNetworkIndex]);
    WiFi.disconnect();
    wifiNetworkIndex = (wifiNetworkIndex + 1) % networkCount;
    wifiConnectionInProgress = false;

    // Wait only after both configured networks have been tried. This makes
    // the fallback attempt start immediately after the primary times out.
    if (!fallbackConfigured || wifiNetworkIndex == 0)
    {
      lastWifiCycleFailureMs = now;
      return false;
    }
  }

  if (lastWifiCycleFailureMs != 0 && now - lastWifiCycleFailureMs < WIFI_RETRY_MS)
  {
    return false;
  }

  // An empty fallback entry is intentionally skipped, so the example
  // configuration keeps working until a second network is configured.
  for (uint8_t checked = 0; checked < networkCount; ++checked)
  {
    if (strlen(ssids[wifiNetworkIndex]) > 0)
    {
      break;
    }
    wifiNetworkIndex = (wifiNetworkIndex + 1) % networkCount;
  }

  if (strlen(ssids[wifiNetworkIndex]) == 0)
  {
    Serial.println("No WiFi SSID configured");
    return false;
  }

  wifiConnectStartedMs = now;
  wifiConnectionInProgress = true;
  Serial.printf("Connecting WiFi SSID '%s'\n", ssids[wifiNetworkIndex]);
  WiFi.mode(WIFI_STA);
  WiFi.begin(ssids[wifiNetworkIndex], passwords[wifiNetworkIndex]);
  return false;
}

static bool syncTime()
{
  if (timeReady)
  {
    return true;
  }

  if (WiFi.status() != WL_CONNECTED)
  {
    return false;
  }

  applyTimezone(alarmConfig.timezone);
  configTime(0, 0, "pool.ntp.org", "time.nist.gov");

  struct tm timeInfo;
  for (uint8_t i = 0; i < 20; ++i)
  {
    if (getLocalTime(&timeInfo, 500))
    {
      timeReady = true;
      Serial.printf("NTP time synchronized: %04d-%02d-%02d %02d:%02d:%02d\n",
                    timeInfo.tm_year + 1900,
                    timeInfo.tm_mon + 1,
                    timeInfo.tm_mday,
                    timeInfo.tm_hour,
                    timeInfo.tm_min,
                    timeInfo.tm_sec);
      return true;
    }
  }

  return false;
}

static String escapeJson(const String &value)
{
  String escaped;
  escaped.reserve(value.length() + 8);
  for (size_t i = 0; i < value.length(); ++i)
  {
    const char c = value[i];
    if (c == '\\' || c == '"')
    {
      escaped += '\\';
    }
    if (c == '\n' || c == '\r')
    {
      escaped += ' ';
    }
    else
    {
      escaped += c;
    }
  }
  return escaped;
}

static bool supabaseRequest(const String &method, const String &path, const String &body, JsonDocument *jsonOut)
{
  if (!hasRealSupabaseConfig() || WiFi.status() != WL_CONNECTED)
  {
    return false;
  }

  const uint32_t now = millis();
  if (lastSupabaseFailureMs != 0 && now - lastSupabaseFailureMs < SUPABASE_FAILURE_BACKOFF_MS)
  {
    return false;
  }

  HTTPClient http;
  const String url = String(SUPABASE_URL) + path;
  Serial.printf("Supabase %s %s (free heap: %u, largest block: %u)\n",
                method.c_str(),
                path.c_str(),
                ESP.getFreeHeap(),
                ESP.getMaxAllocHeap());
  http.begin(url);
  http.setReuse(false);
  http.setTimeout(10000);
  http.addHeader("apikey", SUPABASE_ANON_KEY);
  http.addHeader("Authorization", String("Bearer ") + SUPABASE_ANON_KEY);
  http.addHeader("Content-Type", "application/json");
  // Status responses are discarded. Asking Supabase for no representation
  // avoids allocating response Strings after every 10-second publication.
  http.addHeader("Prefer", method == "POST"
                               ? "return=minimal,resolution=merge-duplicates"
                               : "return=representation");

  int status = 0;
  if (method == "GET")
  {
    status = http.GET();
  }
  else if (method == "POST")
  {
    status = http.POST(body);
  }
  else
  {
    http.end();
    return false;
  }

  String payload;
  if (status < 200 || status >= 300 || jsonOut)
  {
    payload = http.getString();
  }
  http.end();

  if (status < 200 || status >= 300)
  {
    Serial.printf("Supabase %s %s failed: HTTP %d, %s (free heap: %u, largest block: %u)\n",
                  method.c_str(),
                  path.c_str(),
                  status,
                  payload.c_str(),
                  ESP.getFreeHeap(),
                  ESP.getMaxAllocHeap());
    lastSupabaseFailureMs = millis();
    return false;
  }

  if (jsonOut)
  {
    const DeserializationError err = deserializeJson(*jsonOut, payload);
    if (err)
    {
      Serial.printf("Supabase JSON parse failed: %s\n", err.c_str());
      lastSupabaseFailureMs = millis();
      return false;
    }
  }

  lastSupabaseFailureMs = 0;
  return true;
}

static time_t parseLocalAlarmTime(const char *dateText, const char *timeText, const String &timezone)
{
  if (!dateText || !timeText || strlen(dateText) < 10 || strlen(timeText) < 5)
  {
    return 0;
  }

  applyTimezone(timezone);

  struct tm alarmTm = {};
  alarmTm.tm_year = String(dateText).substring(0, 4).toInt() - 1900;
  alarmTm.tm_mon = String(dateText).substring(5, 7).toInt() - 1;
  alarmTm.tm_mday = String(dateText).substring(8, 10).toInt();
  alarmTm.tm_hour = String(timeText).substring(0, 2).toInt();
  alarmTm.tm_min = String(timeText).substring(3, 5).toInt();
  alarmTm.tm_sec = 0;
  alarmTm.tm_isdst = -1;
  return mktime(&alarmTm);
}
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
void loop()
{
  if (!remoteAudioActive)
  {
    ensureWifi();
    syncTime();
  }

  const uint32_t nowMs = millis();
  serviceBraceletEspNow();
  if (!remoteAudioActive)
  {
    stationBatteryVoltage = readStationBatteryVoltage();
  }

  if (nowMs - lastConfigRefreshMs >= CONFIG_REFRESH_MS || lastConfigRefreshMs == 0)
  {
    lastConfigRefreshMs = nowMs;
    if (alarmIsActive())
    {
      // Keep audio.loop() fed during the alarm; HTTPS refreshes can block long enough
      // to underrun streamed audio on the ESP32.
    }
    else if (WiFi.status() == WL_CONNECTED && timeReady)
    {
      refreshConfig();
    }
    else if (!timeReady)
    {
      setStationState(StationState::Fault, ProblemCode::TimeUnknown, "Waiting for NTP time");
    }
  }

  if (bracelet.batteryPercent >= 0 && bracelet.batteryPercent < BRACELET_LOW_BATTERY_PERCENT)
  {
    bracelet.problem = ProblemCode::BraceletLowBattery;
  }

  updateAlarmState();
  flushDeferredStatusPublishes();

  const uint32_t controlSendPeriod = alarmIsActive() ? ACTIVE_CONTROL_SEND_MS : INACTIVE_CONTROL_SEND_MS;
  if (stationControlDirty || nowMs - lastControlSendMs >= controlSendPeriod)
  {
    lastControlSendMs = nowMs;
    sendStationControl();
  }

  if (!remoteAudioActive && (nowMs - lastStatusPublishMs >= STATUS_PUBLISH_MS || lastStatusPublishMs == 0))
  {
    lastStatusPublishMs = nowMs;
    publishStationStatus();
    publishBraceletStatus();
  }

  if (remoteAudioActive)
  {
    serviceRemoteAudio(REMOTE_AUDIO_LOOP_BUDGET_MS);
    delay(0);
  }
  else
  {
    delay(2);
  }
}

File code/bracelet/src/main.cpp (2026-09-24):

#include <Arduino.h>
#include <Preferences.h>
#include <WiFi.h>
#include <Wire.h>
#include <esp_now.h>
#include <esp_system.h>
#include <esp_wifi.h>
#include "SparkFun_BMI270_Arduino_Library.h"
#include "../../bracelet_station_protocol.h"

namespace
{
    namespace Pin
    {
        constexpr uint8_t IMU_SDA = 3;
        constexpr uint8_t IMU_SCL = 2;
        constexpr uint8_t BATTERY_ADC = 1;
        constexpr uint8_t VIBRATION_MOTOR = 0;
    }

    constexpr uint32_t SERIAL_BAUD = 115200;
    constexpr uint32_t SAMPLE_PERIOD_MS = 20;
    constexpr uint32_t SENSOR_RETRY_PERIOD_MS = 2000;
    constexpr uint32_t BATTERY_SAMPLE_PERIOD_MS = 1000;
    constexpr uint32_t TELEMETRY_LOG_PERIOD_MS = 5000;
    constexpr uint32_t ACTIVE_SEND_PERIOD_MS = 200;
    constexpr uint32_t INACTIVE_SEND_PERIOD_MS = 10000;
    constexpr uint32_t CHANNEL_HOP_PERIOD_MS = 300;
    constexpr uint32_t STATION_CONTROL_LOCK_MS = 15000;
    constexpr uint32_t ENERGY_WINDOW_MS = 200;
    constexpr uint32_t VIBRATION_PERIOD_MS = 4000;
    constexpr uint32_t VIBRATION_ON_MS = 500;
    constexpr uint32_t PRE_UNMUTE_SECOND_PULSE_MS = 4000;
    constexpr uint32_t PRE_UNMUTE_THIRD_PULSE_MS = 6000;
    constexpr uint32_t PRE_UNMUTE_SEQUENCE_MS = PRE_UNMUTE_THIRD_PULSE_MS + VIBRATION_ON_MS;
    constexpr uint32_t ALARM_COMPLETE_VIBRATION_LEAD_IN_MS = 200;
    constexpr uint32_t ALARM_COMPLETE_VIBRATION_PERIOD_MS = 300;
    constexpr uint32_t ALARM_COMPLETE_VIBRATION_ON_MS = 150;
    constexpr uint8_t ALARM_COMPLETE_VIBRATION_PULSE_COUNT = 4;
    constexpr uint32_t ALARM_COMPLETE_VIBRATION_SEQUENCE_MS =
        (ALARM_COMPLETE_VIBRATION_PULSE_COUNT - 1) * ALARM_COMPLETE_VIBRATION_PERIOD_MS +
        ALARM_COMPLETE_VIBRATION_ON_MS;
    constexpr uint32_t VIBRATION_SETTLE_MS = 450;
    constexpr float ACCEL_NOISE_FLOOR_G = 0.003F;
    constexpr float GYRO_NOISE_FLOOR_DPS = 0.6F;
    constexpr float ACCEL_ENERGY_SCALE = 60000.0F;
    constexpr float GYRO_ENERGY_SCALE = 8.0F;
    constexpr float BATTERY_DIVIDER_RATIO = 2.0F;
    constexpr float BATTERY_EMPTY_V = 3.30F;
    constexpr float BATTERY_FULL_V = 4.20F;
    constexpr uint8_t LOW_BATTERY_PERCENT = 30;

    constexpr uint8_t BATTERY_UNKNOWN = 255;
    constexpr uint8_t ESP_NOW_MIN_CHANNEL = 1;
    constexpr uint8_t ESP_NOW_MAX_CHANNEL = 13;
    enum class BraceletState : uint8_t
    {
        Ready = 1,
        LowBattery = 2,
        Fault = 3,
    };

    enum class StationState : uint8_t
    {
        Idle = 0,
        Armed = 1,
        Ringing = 2,
        ValidatingActivity = 3,
        Stopped = 4,
        Fault = 5,
        Unknown = 255,
    };

    enum class ProblemCode : uint8_t
    {
        None = 0,
        BraceletLowBattery = 7,
        SensorFault = 8,
    };

    using BraceletStationProtocol::BraceletStatusPacket;
    using BraceletStationProtocol::PacketHeader;
    using BraceletStationProtocol::StationControlPacket;

    struct MotionReading
    {
        float accelX = 0.0F;
        float accelY = 0.0F;
        float accelZ = 1.0F;
        float gyroX = 0.0F;
        float gyroY = 0.0F;
        float gyroZ = 0.0F;
    };

    struct EnergyTracker
    {
        uint32_t windowStartMs = 0;
        uint32_t lastSampleMs = 0;
        uint32_t energy = 0;
        uint16_t validMs = 0;
        uint32_t lastEnergy = 0;
        uint16_t lastValidMs = 0;
        bool baselineReady = false;
    };

    BMI270 imu;
    Preferences preferences;
    MotionReading latestMotion;
    EnergyTracker energyTracker;

    uint8_t deviceId[6] = {};
    uint32_t sequenceNumber = 0;
    uint32_t lastSampleMs = 0;
    uint32_t lastSensorRetryMs = 0;
    uint32_t lastBatterySampleMs = 0;
    uint32_t lastSendMs = 0;
    uint32_t lastLogMs = 0;
    uint32_t lastEspNowDebugMs = 0;
    uint32_t lastStationControlMs = 0;
    uint32_t lastChannelHopMs = 0;
    uint32_t ignoreMotionUntilMs = 0;
    uint32_t vibrationRequestStartMs = 0;
    uint32_t alarmCompleteVibrationStartMs = 0;
    uint32_t bootSessionId = 0;
    uint32_t movementEventId = 0;
    uint32_t movementEventUptimeMs = 0;
    uint32_t movementEventEnergy = 0;
    uint16_t movementEventValidMs = 0;
    uint32_t acknowledgedMovementEventId = 0;
    uint32_t activeVibrationRequestId = 0;
    uint32_t vibrationAckId = 0;
    uint32_t lastReceivedControlSequence = 0;

    bool sensorReady = false;
    bool espNowReady = false;
    bool stationPaired = false;
    bool forceStatusSend = false;
    bool vibrationMotorOn = false;
    bool alarmCompleteVibrationActive = false;
    float batteryVoltage = 0.0F;
    uint8_t batteryPercent = BATTERY_UNKNOWN;
    StationState stationState = StationState::Unknown;
    BraceletState lastSentBraceletState = BraceletState::Fault;
    ProblemCode lastSentProblemCode = ProblemCode::None;
    bool lastSentVibrating = false;
    bool stationRequestsVibration = false;
    uint8_t espNowChannel = ESP_NOW_MIN_CHANNEL;
    uint8_t pairedStationId[6] = {};
    StationControlPacket pendingStationControl = {};
    bool stationControlPending = false;
    portMUX_TYPE espNowMux = portMUX_INITIALIZER_UNLOCKED;

    const uint8_t BROADCAST_PEER[ESP_NOW_ETH_ALEN] = {0xff, 0xff, 0xff, 0xff, 0xff, 0xff};

    bool beginBmi270()
    {
        const uint8_t addresses[] = {BMI2_I2C_PRIM_ADDR, BMI2_I2C_SEC_ADDR};

        for (uint8_t address : addresses)
        {
            if (imu.beginI2C(address, Wire) == BMI2_OK)
            {
                Serial.print("bmi270_address:0x");
                Serial.println(address, HEX);
                return true;
            }
        }

        Serial.println("bmi270_status:not_found");
        return false;
    }

    float readBatteryVoltage()
    {
        const uint32_t measuredMillivolts = analogReadMilliVolts(Pin::BATTERY_ADC);
        return (static_cast<float>(measuredMillivolts) * BATTERY_DIVIDER_RATIO) / 1000.0F;
    }

    uint8_t estimateBatteryPercent(float voltage)
    {
        if (voltage <= 0.1F)
        {
            return BATTERY_UNKNOWN;
        }

        const float ratio = (voltage - BATTERY_EMPTY_V) / (BATTERY_FULL_V - BATTERY_EMPTY_V);
        const int percent = static_cast<int>(roundf(constrain(ratio, 0.0F, 1.0F) * 100.0F));
        return static_cast<uint8_t>(percent);
    }

    bool isBatteryLow()
    {
        return batteryPercent != BATTERY_UNKNOWN && batteryPercent < LOW_BATTERY_PERCENT;
    }

    void updateBattery()
    {
        const uint32_t now = millis();
        if (now - lastBatterySampleMs < BATTERY_SAMPLE_PERIOD_MS)
        {
            return;
        }

        lastBatterySampleMs = now;
        batteryVoltage = readBatteryVoltage();
        batteryPercent = estimateBatteryPercent(batteryVoltage);
    }

    float noiseFilteredAbs(float value, float noiseFloor)
    {
        const float magnitude = fabsf(value);
        return magnitude <= noiseFloor ? 0.0F : magnitude - noiseFloor;
    }
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

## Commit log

2026-04-30 Add project agent guides and architecture contracts
    [bracelet.kicad_pcb, bracelet.kicad_sch]
2026-04-30 Add schematic file for hp box
    [boite hp.kicad_pcb, boite hp.kicad_sch]
2026-05-03 Design bracelet PCB
    [boite hp.kicad_sch, bracelet.kicad_pcb, bracelet.kicad_sch]
2026-05-04 Add boite hp schema
    [boite hp.kicad_pcb, boite hp.kicad_sch]
2026-05-08 Update Architecture db
    [boite hp.kicad_pcb, boite hp.kicad_sch, bracelet.kicad_pcb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]
2026-08-02 Complete PWA icons and alarm flow
2026-08-05 Improve bracelet WiFi telemetry and antenna validation
2026-08-28 Migrate alarm system to ESP-NOW and refine wake flow
2026-09-24 Adjust bracelet vibration warnings
    [main.cpp]
2026-10-05 Add project presentation and CAD assets
    [Boite resonance.step, Box bracelet.step, Cache station.step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]
